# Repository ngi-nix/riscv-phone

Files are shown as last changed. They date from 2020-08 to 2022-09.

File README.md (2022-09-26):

# RISC-V Phone

This flake packages the firmware for the Freedom E310 and the Espressif ESP32 SoCs.

It is currently based against $HEAD of upstream for the [source files](http://majstor.org/gitweb/?p=rvPhone.git;a=tree).

If anything breaks, you can always pin the `riscvphone-src` input to a working revision:

```
url = "git://majstor.org/rvPhone.git?rev=38e19a65fda7a37688320b4b732eb1113bbcbad7";
```
You may find more information about this project [here](http://majstor.org/rvphone/) and [here](http://majstor.org/rvphone/build.html).

For further details, please refer to the documentation in the flake itself.

## Building

To build the firmware for each SoC (and possibly also flash it), type `nix build .#fe310` or `nix build .#esp32`.

## Developing

You can enter a developer shell by typing `nix develop .#fe310` or `nix develop .#esp32`. 

Navigate into `fw/fe310` or `fw/esp32` and type `make` to compile. Typing `make clean` will delete the compiled files.

When typing `make` in `fw/esp32`, a configuration menu will open if no `sdkconfig` configuration file exists, even if empty. You can manually choose the configuration values in this menu at any time by typing `make menuconfig` or pass them automatically via the [sdkconfig.defaults](https://docs.espressif.com/projects/esp-idf/en/latest/esp32/api-reference/kconfig.html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) file.

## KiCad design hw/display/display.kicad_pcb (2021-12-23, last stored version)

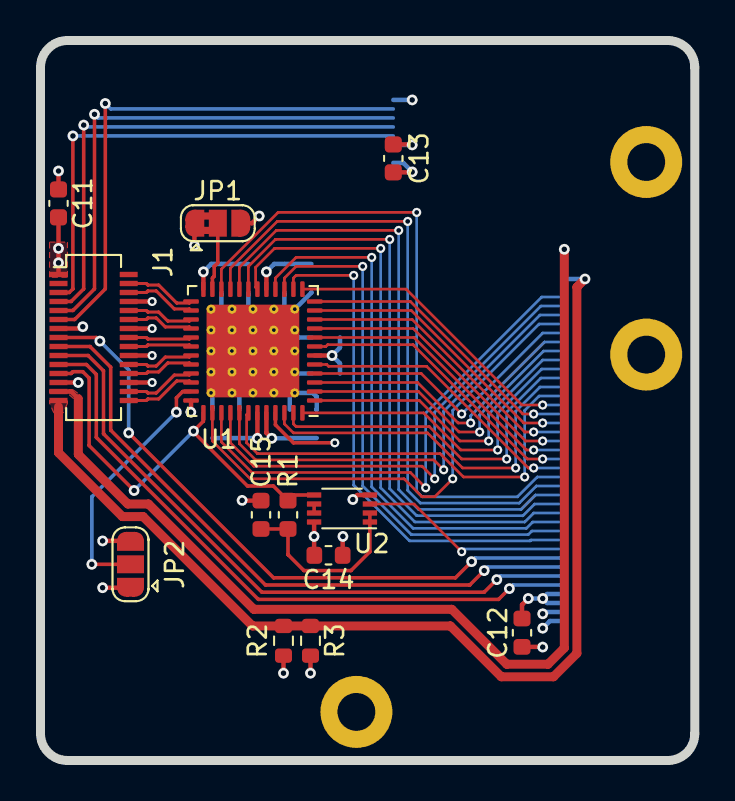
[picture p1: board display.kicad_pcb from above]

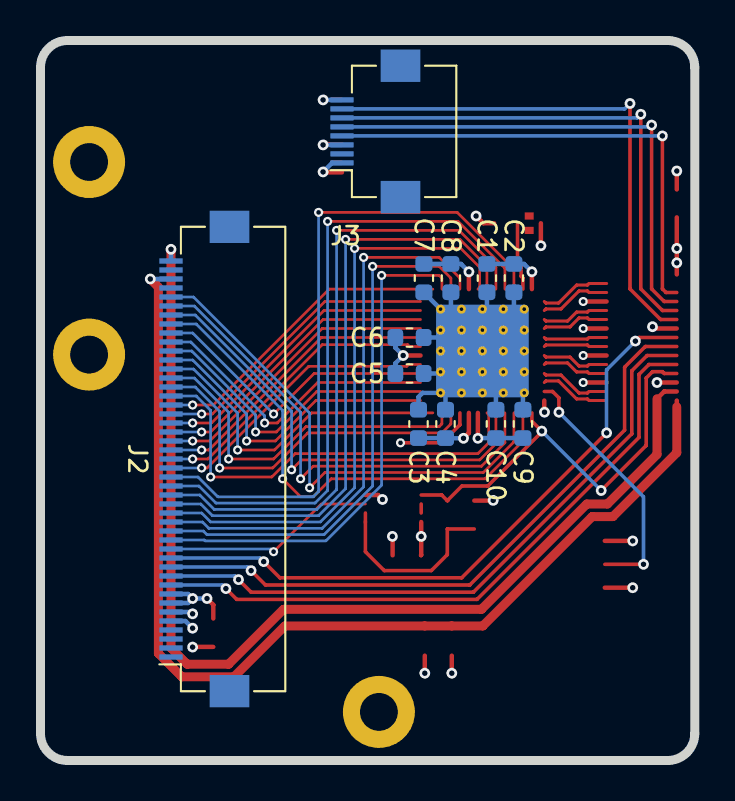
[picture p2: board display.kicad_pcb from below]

Board: 4 copper layers, 36.3 x 40.0 mm, 28 parts (12 on the bottom side), 56 nets.

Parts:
C1, C3, C5, C7, C9, C12, C13, C14, C15: 0.1uF; C_0603_1608Metric
C2, C4, C6, C8, C10: 0.01uF; C_0603_1608Metric
C11: 10uF; C_0603_1608Metric
J1: Input; Molex_SlimStack_55560-0301_2x15_P0.50mm_Vertical
J2: Display; Hirose_FH12-45S-0.5SH_1x45-1MP_P0.50mm_Horizontal
J3: Touch; Hirose_FH12-8S-0.5SH_1x08-1MP_P0.50mm_Horizontal
J4, J5, J6: Spacer
JP1: CLK_POL; SolderJumper-3_P1.3mm_Bridged2Bar12_RoundedPad1.0x1.5mm
JP2: SLEW; SolderJumper-3_P1.3mm_Open_RoundedPad1.0x1.5mm
R1: 10K; R_0603_1608Metric
R2, R3: DNP; R_0603_1608Metric
U1: SN65LVDS822; QFN-48-1EP_7x7mm_P0.5mm_EP5.15x5.15mm_ThermalVias
U2: 74AUP2G132DC; VSSOP-8_2.3x2mm_P0.5mm

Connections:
+3V3: C1.1, C2.1, C3.1, C4.1, C5.1, C6.1, C7.1, C8.1, C9.1, C10.1, C11.1, C12.1, C13.1, C14.1, J1.1, J2.7, J2.8, J3.3, JP1.1, JP2.1, U1.6, U1.17, U1.24, U1.43, U1.44, U2.8
/DISP_B0: J2.37, U1.4
/DISP_B1: J2.36, U1.3
/DISP_B2: J2.35, U1.2
/DISP_B3: J2.34, U1.1
/DISP_B4: J2.33, U1.48
/DISP_B5: J2.32, U1.47
/DISP_B6: J2.31, U1.46
/DISP_B7: J2.30, U1.42
/DISP_DE: J2.38, U1.38
/DISP_G0: J2.29, U1.13
/DISP_G1: J2.28, U1.12
/DISP_G2: J2.27, U1.11
/DISP_G3: J2.26, U1.10
/DISP_G4: J2.25, U1.9
/DISP_G5: J2.24, U1.8
/DISP_G6: J2.23, U1.7
/DISP_G7: J2.22, U1.5
/DISP_HSYNC: J2.40, U1.40
/DISP_PCLK: J2.39, U1.41
/DISP_R0: J2.21, U1.22
/DISP_R1: J2.20, U1.21
/DISP_R2: J2.19, U1.20
/DISP_R3: J2.18, U1.19
/DISP_R4: J2.17, U1.18
/DISP_R5: J2.16, U1.16
/DISP_R6: J2.15, U1.15
/DISP_R7: J2.14, U1.14
/DISP_RST: J2.13, U2.3
/DISP_VSYNC: J2.41, U1.39
/LVDS_A0N: J1.4, U1.25
/LVDS_A0P: J1.6, U1.26
/LVDS_A1N: J1.10, U1.27
/LVDS_A1P: J1.12, U1.28
/LVDS_A2N: J1.16, U1.29
/LVDS_A2P: J1.18, U1.30
/LVDS_A3N: J1.28, U1.33
/LVDS_A3P: J1.30, U1.34
/LVDS_CLKN: J1.22, U1.31
/LVDS_CLKP: J1.24, U1.32
CTP.INT: J1.9, J3.6
CTP.RST: J1.11, J3.7
CTP.SCL: J1.5, J3.4
CTP.SDA: J1.7, J3.5
ENABLE: J1.23, R1.2, U1.37, U2.5
GND: C1.2, C2.2, C3.2, C4.2, C5.2, C6.2, C7.2, C8.2, C9.2, C10.2, C11.2, C12.2, C13.2, C14.2, C15.2, J1.8, J1.13, J1.14, J1.20, J1.25, J1.26, J2.5, J2.6, J3.1, J3.8, J4.1, J5.1, J6.1, JP1.3, JP2.3, R2.2, R3.2, U1.36, U1.45, U1.49, U2.4
LED_A: J1.27, J2.45
LED_K: J1.29, J2.43, R2.1, R3.1
unnamed: C15.1, R1.1, U2.1, U2.2
unnamed: JP1.2, U1.23
unnamed: JP2.2, U1.35
unnamed: U2.6, U2.7
SPI.CS: J1.15, J2.12
SPI.MISO: J1.21, J2.9
SPI.MOSI: J1.19, J2.10
SPI.SCK: J1.17, J2.11

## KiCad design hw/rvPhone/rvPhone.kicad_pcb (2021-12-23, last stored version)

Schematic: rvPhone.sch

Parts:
C1: 1uF; C_0603_1608Metric
C2: 0.047uF; C_0603_1608Metric
C3: 4.7uF; C_0603_1608Metric
C4, C5, C6, C7, C8, C9, C10, C11, C21, C22, C36, C38, C41, C42, C50, C53, C54: 10uF; C_0603_1608Metric
C12: 47uF; C_0805_2012Metric
C13, C15, C16, C17, C18, C19, C20, C23, C24, C27, C28, C29, C30, C31, C32, C33, C34, C35, C37, C39, C40, C43, C44, C45, C46: 0.1uF; C_0603_1608Metric
C14: 0.01uF; C_0603_1608Metric
C25, C26: 10pF; C_0603_1608Metric
C51, C52, C55: 22uF; C_0805_2012Metric
D1: B5817WS; D_SOD-323
D2: LED; LED_0603_1608Metric
J1: USB_OTG; GCT_MicroUSB-USB3080
J2: BATT; PinHeader_1x02_P2.54mm_Vertical
J3: +5V; PinHeader_1x02_P2.54mm_Vertical
J4: AudioJack; 35RASMT4BHNTRX
J5: SPEAKER; PinHeader_1x04_P2.54mm_Vertical
J6: Ext Audio; Molex_SlimStack_54722-0164_2x08_P0.50mm_Vertical
JP1: AUDIO PWR; SolderJumper-3_P1.3mm_Open_RoundedPad1.0x1.5mm
L1: 2.2uH; L_Vishay_IHLP-2525
L2: 2.2uH; Coilcraft-LPS3015
L3: 1uH; Coilcraft-XAL40
R1: 260R; R_0603_1608Metric
R2: 5.23K; R_0603_1608Metric
R3: 30.1K; R_0603_1608Metric
R4: 2.2K; R_0603_1608Metric
R5: 560K; R_0603_1608Metric
R6: 180K; R_0603_1608Metric
R7, R8, R9, R10, R11, R15, R16, R18, R19, R20, R21, R22, R23, R24, R25, R26, R30, R34, R35: 100K; R_0603_1608Metric
R12: 100R; R_0603_1608Metric
R13, R14, R33: 10K; R_0603_1608Metric
R17, R28, R29: 47K; R_0603_1608Metric
R27: 210K; R_0603_1608Metric
R31: 50K; R_0603_1608Metric
R32: 0R; R_0603_1608Metric
SW1: RESET; SW_SPST_PTS810
SW2: WAKE; Panasonic_EVPAE
TP2: PMU_OUT0; TestPoint_Pad_D1.5mm
U1: BQ25895; Texas_S-PWQFN-N24_EP2.7x2.7mm_ThermalVias
U2: TPS62293; TPS62290
U3: TPS630250
U4: FE310-G002; QFN-48-1EP_6x6mm_P0.4mm_EP4.2x4.2mm_ThermalVias
U5: IS25LP128-JKLE; WSON-8-1EP_6x5mm_P1.27mm_EP3.4x4mm
U6: SN74LVC2G07DCK; Texas_R-PDSO-G6
U7: TMUX1574RSV; UQFN-16_1.8x2.6mm_P0.4mm
U8, U9: 74HC00; DHVQFN-14_2.5x3.0mm_P0.5mm_EP1.0x1.5mm
U10, U11: 74HC595; DHVQFN-16_2.5x3.5mm_P0.5mm_EP1.0x2.0mm
U12: ICS-43434
U13, U14: MAX98357A; TQFN-16-1EP_3x3mm_P0.5mm_EP1.23x1.23mm_ThermalVias
U15, U16: MAX14689A; TDFN-10-1EP_2x2.5mm_P0.4mm_EP1.3x1.4mm_ThermalVias
U17: SN74LVC1G04DCK; Texas_R-PDSO-G5
U18: TMUX1119DCK; Texas_R-PDSO-G6
U19: 74LVC1G02; Texas_R-PDSO-G5
U20: SN74LVC2G66DCU; VSSOP-8_2.3x2mm_P0.5mm
X1: SiT1533
Y1: 16MHz; TXC_7M

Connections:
+1V8: C9.1, C19.1, C20.1, C21.1, C55.1, L2.2, R12.1, U2.3 (FB), U4.6 (VDD), U4.30 (VDD), U4.46 (VDD); also elsewhere on the board
+VSYS: C4.1, C5.1, C8.1, C10.1, D2.2 (A), L1.2, U1.8 (OTG), U1.15 (SYS), U1.16 (SYS), U2.4 (EN), U2.5 (VIN), U3.4 (VIN), U3.5 (VIN), U3.6 (VIN), U3.7 (VINA), U3.8 (EN); also elsewhere on the board
/AON_PMU_OUT_0: TP2.1, U4.22 (AON_PMU_OUT_0)
/AON_PMU_OUT_1: U4.17 (AON_PMU_OUT_1)
/AUDIO_OUT_L+: U13.9 (OUTP), U15.3
/AUDIO_OUT_L-: U13.10 (OUTN), U15.10
/AUDIO_OUT_R+: U14.9 (OUTP), U16.3
/AUDIO_OUT_R-: U14.10 (OUTN), U16.10
/BQ_QON: U1.12 (/QON), U6.4 (2Y)
/BQ_SW: C2.1, D1.2 (A), L1.1, U1.19 (SW), U1.20 (SW)
/EXT_AUDIO_EN: J6.10, U19.4
/HP_DET: J4.RN, J4.TN, R30.1, U17.2 (A)
/HP_L: C42.2, U15.5
/HP_R: C41.2, U16.5
/MIC_CLK: R23.2, U7.11 (S4B), U8.1, U9.12, U9.13, U12.4 (SCK)
/MIC_SD: U12.6 (SD), U20.2
/MIC_WS: R21.2, U7.1 (S1B), U12.1 (WS)
/PLL_AVDD: C23.1, C24.1, R12.2, U4.7 (PLL_AVDD)
/PLL_AVSS: C23.2, C24.2, U4.8 (PLL_AVSS)
/PSD_LFALTCLK: U4.20 (AON_PSD_LFALTCLK), X1.3 (CLKOUT)
/QSPI_CLK: U4.48 (QSPI_CLK), U5.6 (SCK)
/QSPI_CS: R8.2, U4.5 (QSPI_CS), U5.1 (S#)
/QSPI_DQ_0: U4.4 (QSPI_DQ_0), U5.5 (MOSI/IO0)
/QSPI_DQ_1: U4.3 (QSPI_DQ_1), U5.2 (MISO/IO1)
/QSPI_DQ_2: U4.2 (QSPI_DQ_2), U5.3 (WP#/IO2)
/QSPI_DQ_3: R9.2, U4.1 (QSPI_DQ_3), U5.7 (HOLD#/IO3)
/RESET: C14.1, R10.1, SW1.2, U4.24 (AON_ERST_N), U6.6 (1Y)
/SD_IN: U7.4 (S2B), U11.9, U13.1 (DIN), U14.1 (DIN)
/SD_OUT: R22.2, U7.8 (S3B), U10.14, U20.1
/SPK_CLK: U9.11, U13.16 (BCLK), U14.16 (BCLK)
/SPK_EN: C39.1, C40.1, R27.2, U7.15 (SEL), U8.8, U9.4, U9.5, U13.4 (SD_MODE), U15.2, U16.2, U19.1
/SPK_GAIN: U13.2 (GAIN_SLOT), U14.2 (GAIN_SLOT), U18.5
/SPK_GAIN_SEL: U9.8, U18.1
/SPK_L+: J5.1, J6.5, J6.7, U15.1
/SPK_L-: J5.2, J6.9, J6.11, U15.8
/SPK_R+: J5.3, U16.1
/SPK_R-: J5.4, U16.8
/XTAL_XI: C25.1, U4.9 (16M_XTAL_XI), Y1.1
/XTAL_XO: C26.1, U4.10 (16M_XTAL_XO), Y1.2
/~HP_DET: U9.9, U15.7, U16.7, U17.4 (Y)
BQ.INT: U1.7 (INT); also elsewhere on the board
BT81X.AUDIO: J6.6; also elsewhere on the board
BT81X.GPIO2: U9.10, U19.2; also elsewhere on the board
BT81X.INT: R16.1, U7.12 (S4A); also elsewhere on the board
CTP.RST: R15.1, U7.16 (S1A); also elsewhere on the board
DISP_CS: U9.3; also elsewhere on the board
GND: C1.2, C3.2, C4.2, C5.2, C6.2, C7.2, C8.2, C9.2, C10.2, C11.2, C12.2, C13.2, C14.2, C15.2, C16.2, C17.2, C18.2, C19.2, C20.2, C21.2, C22.2, C25.2, C26.2, C27.2, C28.2, C29.2, C30.2, C31.2, C32.2, C33.2, C34.2, C35.2, C36.2, C37.2, C38.2, C39.2, C40.2, C43.2, C44.2, C45.2, C46.2, C50.2, C51.2, C52.2, C53.2, C54.2, C55.2, J1.5 (GND), J2.2, J3.2, J4.S, J6.1, J6.3, R1.2, R3.2, R6.2, R18.1, R19.1, R20.1, R21.1, R22.1, R23.1, R26.1, R28.2, R29.2, R32.2, R33.2, R34.1, R35.1, SW1.1, SW2.1, U1.9 (/CE), U1.17 (PGND), U1.18 (PGND), U1.25 (EP), U2.2 (MODE), U2.6 (GND), U2.7 (EP), U3.2 (PGND), U3.9 (GND), U3.10 (PFM), U4.21 (AON_PSD_LFCLKSEL), U4.49 (GND), U5.4 (VSS), U5.9 (EP), U6.2 (GND), U7.6 (GND), U7.13 (/EN), U8.7 (GND), U8.15, U9.7 (GND), U9.15, U10.8, U10.12, U10.17, U11.8, U11.12, U11.17, U12.2 (LR), U12.3 (GND), U13.3 (GND), U13.11 (GND), U13.15 (GND), U13.17 (EP), U14.3 (GND), U14.11 (GND), U14.15 (GND), U14.17 (EP), U15.4, U15.9, U15.11, U16.4, U16.9, U16.11, U17.3 (GND), U18.3, U19.3, U20.3, U20.4, U20.5, U20.6, X1.2 (GND), Y1.3; also elsewhere on the board
GPIO_0: U4.25 (GPIO_0/PWM0.0); also elsewhere on the board
GPIO_16: U4.38 (GPIO_16/UART0.RX), U7.7 (D3)
GPIO_17: U4.39 (GPIO_17/UART0.TX), U7.5 (D2)
GPIO_18: R19.2, U4.40 (GPIO_18), U8.5, U8.12, U8.13
GPIO_20: U4.42 (GPIO_20/PWM1.0); also elsewhere on the board
GPIO_22: U4.44 (GPIO_22/PWM1.3); also elsewhere on the board
GPIO_23: R18.2, U4.45 (GPIO_23); also elsewhere on the board
I2C0.SCL: R13.2, U1.5 (SCL), U4.37 (GPIO_13/PWM2.3); also elsewhere on the board
I2C0.SDA: R14.2, U1.6 (SDA), U4.36 (GPIO_12/PWM2.2); also elsewhere on the board
JTAG_TCK: U4.13 (JTAG_TCK); also elsewhere on the board
JTAG_TDI: U4.16 (JTAG_TDI); also elsewhere on the board
JTAG_TDO: U4.14 (JTAG_TDO); also elsewhere on the board
JTAG_TMS: U4.15 (JTAG_TMS); also elsewhere on the board
JTAG_TRST_N: R7.2, U6.1 (1A); also elsewhere on the board
unnamed: C2.2, U1.21 (BTST)
unnamed: C3.1, R2.1, U1.22 (REGN)
unnamed: C6.1, C7.1, J2.1, U1.13 (BAT), U1.14 (BAT)
unnamed: C41.1, J4.R, R28.1
unnamed: C42.1, J4.T, R29.1
unnamed: D2.1 (K), R4.2
unnamed: L2.1, U2.1 (SW)
unnamed: L3.1, U3.3 (L1)
unnamed: L3.2, U3.1 (L2)
unnamed: R1.1, U1.10 (ILIM)
unnamed: R2.2, R3.1, R33.1, U1.11 (TS)
unnamed: R4.1, U1.4 (STAT)
unnamed: R5.2, R6.1, U3.11 (FB)
unnamed: R27.1, U14.4 (SD_MODE)
unnamed: R31.2, U18.6
unnamed: R32.1, U18.4
unnamed: U1.2 (D+), U1.3 (D-)
unnamed: U8.3, U8.4
unnamed: U8.10, U8.11
unnamed: U9.2, U9.6
unnamed: U10.9, U11.14
unnamed: U8.6, U10.11, U11.11
PWM0.1: U4.26 (GPIO_1/PWM0.1), U7.10 (D4)
PWM1.1: U4.41 (GPIO_19/PWM1.1), U7.2 (D1)
PWM1.2: R17.2, U4.43 (GPIO_21/PWM1.2), U8.2, U8.9, U20.7
PWM2.1: R20.2, U4.35 (GPIO_11/PWM2.1), U9.1, U13.14 (LRCLK), U14.14 (LRCLK)
SPI1.MISO: R24.2, U4.29 (GPIO_4/SPI1.MISO); also elsewhere on the board
SPI1.MOSI: R25.2, U4.28 (GPIO_3/SPI1.MOSI/PWM0.3); also elsewhere on the board
SPI1.SCK: R26.2, U4.31 (GPIO_5/SPI1.SCK); also elsewhere on the board
SPI1.SS0: U4.27 (GPIO_2/SPI1.SS0/PWM0.2); also elsewhere on the board
SPI1.SS2: U4.33 (GPIO_9/SPI1.SS2); also elsewhere on the board
SPI1.SS3: U4.34 (GPIO_10/SPI1.SS3/PWM2.0); also elsewhere on the board
UART0.RXD: R35.2, U7.9 (S3A); also elsewhere on the board
UART0.TXD: R34.2, U7.3 (S2A); also elsewhere on the board
USB_D+: J1.3 (D+); also elsewhere on the board
USB_D-: J1.2 (D-); also elsewhere on the board
VBUS: C1.1, C50.1, J1.1 (VBUS), U1.1 (VBUS); also elsewhere on the board
WAKE: R11.1, SW2.2, U4.18 (AON_PMU_DWAKEUP_N), U6.3 (2A); also elsewhere on the board

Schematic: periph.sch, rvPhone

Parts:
C201, C204, C205, C206, C207, C208, C209, C210, C211, C212, C213, C214, C219, C220, C223, C224, C226, C227, C229, C230, C231: 0.1uF; C_0603_1608Metric
C202, C228: 22uF; C_0805_2012Metric
C203, C221, C222: 1uF; C_0603_1608Metric
C215, C216, C217: 33pF; C_0603_1608Metric
C218: 470uF; CP_EIA-7343-31_Kemet-D
C225: 0.01uF; C_0603_1608Metric
J201: Modem; TE_mPCIe-1775862
J202: SIM_Card; Wurth_NanoSIM-693043020611
J203: Motor; SolderWirePad_1x02_SMD_1x2mm
J204: Micro_SD_Card_Det; Molex_MicroSD-5027740891
J205: Prog; Hirose_FH12-12S-0.5SH_1x12-1MP_P0.50mm_Horizontal
J206: Expansion; Molex_SlimStack_54722-0164_2x08_P0.50mm_Vertical
J207: Camera; Molex_SlimStack_54722-0164_2x08_P0.50mm_Vertical
J208, J209: Spacer; Spacer_small
JP201: PCM_EN; SolderJumper-3_P1.3mm_Bridged2Bar12_RoundedPad1.0x1.5mm
JP202: SIMCom_EN; SolderJumper-3_P1.3mm_Bridged2Bar12_RoundedPad1.0x1.5mm
JP203: Q.DTR; SolderJumper-2_P1.3mm_Open_RoundedPad1.0x1.5mm
JP204: Q.RI; SolderJumper-2_P1.3mm_Open_RoundedPad1.0x1.5mm
JP205: Q.RXD; SolderJumper-2_P1.3mm_Open_RoundedPad1.0x1.5mm
JP206: Q.TXD; SolderJumper-2_P1.3mm_Open_RoundedPad1.0x1.5mm
R201, R209: 10K; R_0603_1608Metric
R202, R203, R207: 47K; R_0603_1608Metric
R204, R205, R206: 22R; R_0603_1608Metric
R208: 4.7K; R_0603_1608Metric
SW201: ESP32_RST; SW_SPST_PTS810
SW202: MODEM_RST; SW_SPST_PTS810
U201: ESP32-WROOM
U202: SN74CBTLV3125RGY; Texas_S-PVQFN-N14_ThermalVias
U203, U204: TXB0104RGY; Texas_S-PVQFN-N14_ThermalVias
U205: DRV2605LDGS; VSSOP-10_3x3mm_P0.5mm
U206: LSM9DS1; LGA-24L_3x3.5mm_P0.43mm
U207: FT230XQ; QFN-16-1EP_4x4mm_P0.65mm_EP2.1x2.1mm
U208: TMUX154ERSW; UQFN-10_1.4x1.8mm_P0.4mm

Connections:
+1V8: C206.1, C208.1, JP201.1, JP202.1, U203.1 (VCCA), U204.1 (VCCA); also elsewhere on the board
+VSYS: J207.2, J207.4; also elsewhere on the board
/periph/ESP32_EN: C203.1, C219.1, R201.2, SW201.1, U201.3 (EN)
/periph/ESP32_PCM_CLK: U201.9 (IO33), U203.13 (B1)
/periph/ESP32_PCM_DI: U201.6 (IO34), U203.12 (B2)
/periph/ESP32_PCM_DO: U201.24 (IO2), U203.11 (B3)
/periph/ESP32_PCM_SYNC: U201.26 (IO4), U203.10 (B4)
/periph/ESP32_UART2_DTR: JP203.1, U201.8 (IO32), U204.12 (B2)
/periph/ESP32_UART2_RI: JP204.1, U201.7 (IO35), U204.13 (B1)
/periph/ESP32_UART2_RXD: JP206.1, U201.28 (IO17), U204.11 (B3)
/periph/ESP32_UART2_TXD: JP205.1, U201.27 (IO16), U204.10 (B4)
/periph/ESP32_VSPI_MISO: U201.31 (IO19), U202.5 (2A)
/periph/ESP32_VSPI_MOSI: U201.37 (IO23), U202.9 (3A)
/periph/ESP32_VSPI_SCK: U201.30 (IO18), U202.12 (4A)
/periph/ESP32_VSPI_SS0: R202.2, U201.29 (IO5), U202.3 (1B)
/periph/PCM_CLK: J201.45, U203.2 (A1)
/periph/PCM_DI: J201.49, U203.4 (A3)
/periph/PCM_DO: J201.47, U203.3 (A2)
/periph/PCM_SYNC: J201.51, U203.5 (A4)
/periph/PERST: C220.1, J201.22, SW202.1
/periph/Quectel_UART_DTR: J201.31, JP203.2
/periph/Quectel_UART_RI: J201.17, JP204.2, U204.5 (A4)
/periph/Quectel_UART_RXD: J201.11, JP205.2
/periph/Quectel_UART_TXD: J201.13, JP206.2
/periph/SIMCom_UART_DTR: J201.46, U204.3 (A2)
/periph/SIMCom_UART_RI: J201.44, U204.2 (A1)
/periph/SIMCom_UART_TXD: J201.19, U204.4 (A3)
/periph/USB_CBUS0: U207.12 (CBUS0), U208.8 (/EN)
/periph/USB_CBUS1: U207.11 (CBUS1), U208.10 (SEL)
/periph/USB_CBUS3: R208.2, R209.1, U207.14 (CBUS3)
/periph/USB_RXD: U207.2 (RXD), U208.5 (B)
/periph/USB_TXD: U207.15 (TXD), U208.3 (A)
BQ.INT: U201.10 (IO25); also elsewhere on the board
BT81X.GPIO0: J207.10; also elsewhere on the board
BT81X.GPIO3: U205.4 (IN/TRIG); also elsewhere on the board
ESP32.HSPI.MISO: U201.14 (IO12); also elsewhere on the board
ESP32.HSPI.MOSI: U201.16 (IO13); also elsewhere on the board
ESP32.HSPI.SCK: U201.13 (IO14); also elsewhere on the board
ESP32.HSPI.SS0: U201.23 (IO15); also elsewhere on the board
ESP32.IO26: U201.11 (IO26); also elsewhere on the board
ESP32.IO27: U201.12 (IO27); also elsewhere on the board
ESP32.UART0.RXD: J205.1, U201.34 (RXD0), U208.2 (A1)
ESP32.UART0.TXD: J205.2, U201.35 (TXD0), U208.6 (B1)
GND: C201.2, C202.2, C203.2, C204.2, C205.2, C206.2, C207.2, C208.2, C209.2, C210.2, C211.2, C212.2, C213.2, C214.2, C215.2, C216.2, C217.2, C218.2, C219.2, C220.2, C221.2, C222.2, C223.2, C224.2, C225.2, C226.2, C227.2, C228.2, C229.2, C230.2, C231.2, J201.4, J201.9, J201.15, J201.18, J201.21, J201.26, J201.27, J201.29, J201.34, J201.35, J201.37, J201.40, J201.43, J201.50, J201.53, J202.5 (GND), J204.6, J204.11, J205.3, J205.9, J206.6, J206.11, J206.16, J207.6, J207.11, J207.16, J208.1, J209.1, JP201.3, JP202.3, R209.2, SW201.2, SW202.2, U201.1 (GND), U201.15 (GND), U201.38 (GND), U201.39 (EP), U202.2 (1A), U202.7 (GND), U202.15 (EP), U203.7 (GND), U203.15 (Pad), U204.7 (GND), U204.15 (Pad), U205.8 (GND), U206.14 (RES), U206.15 (RES), U206.16 (RES), U206.17 (RES), U206.18 (RES), U206.19 (GND), U206.20 (GND), U207.3 (GND), U207.4 (~CTS), U207.13 (GND), U207.17 (GND), U208.4 (GND); also elsewhere on the board
GPIO_0: J204.2, R207.2; also elsewhere on the board
GPIO_20: U201.36 (IO22); also elsewhere on the board
GPIO_22: U201.33 (IO21); also elsewhere on the board
I2C0.SCL: J206.14, J207.14, U205.2 (SCL), U206.2 (SCL/SPC); also elsewhere on the board
I2C0.SDA: J206.12, J207.12, U205.3 (SDA), U206.4 (SDA/SDI/SDO); also elsewhere on the board
JTAG_TCK: J205.4; also elsewhere on the board
JTAG_TDI: J205.7; also elsewhere on the board
JTAG_TDO: J205.5; also elsewhere on the board
JTAG_TMS: J205.6; also elsewhere on the board
JTAG_TRST_N: J205.8; also elsewhere on the board
unnamed: C214.1, J201.8, J202.1 (VCC)
unnamed: C215.1, J202.2 (RST), R206.1
unnamed: C216.1, J202.3 (CLK), R205.1
unnamed: C217.1, J202.7 (I/O), R204.1
unnamed: C222.1, U205.1 (REG)
unnamed: C225.1, U206.21 (CAP)
unnamed: C226.1, U206.24 (C1)
unnamed: J201.10, R204.2
unnamed: J201.12, R205.2
unnamed: J201.14, R206.2
unnamed: J203.1, U205.7 (OUT+)
unnamed: J203.2, U205.9 (OUT-)
unnamed: JP201.2, U203.8 (OE)
unnamed: JP202.2, U204.8 (OE)
SPI1.MISO: J204.7, J206.7, J207.7, U202.6 (2B); also elsewhere on the board
SPI1.MOSI: J204.3, J206.5, J207.5, U202.8 (3B); also elsewhere on the board
SPI1.SCK: J204.5, J206.9, J207.9, U202.11 (4B); also elsewhere on the board
SPI1.SS0: R203.2, U202.1 (/1OE), U202.4 (/2OE), U202.10 (/3OE), U202.13 (/4OE); also elsewhere on the board
SPI1.SS2: J207.8; also elsewhere on the board
UART0.RXD: J205.11, J206.15, U208.1 (A0); also elsewhere on the board
UART0.TXD: J205.10, J206.13, U208.7 (B0); also elsewhere on the board
USB_D+: U207.6 (USBDP); also elsewhere on the board
USB_D-: U207.7 (USBDM); also elsewhere on the board
VBUS: R208.1; also elsewhere on the board
WAKE: U201.25 (IO0); also elsewhere on the board
iMX8.USB1.D_N: J201.36; also elsewhere on the board
iMX8.USB1.D_P: J201.38; also elsewhere on the board

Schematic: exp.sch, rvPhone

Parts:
C301: 4.7uF; C_0603_1608Metric
C302, C303, C304, C305, C306, C307, C308, C309, C310, C311, C312, C313, C319: 0.1uF; C_0603_1608Metric
C314, C315, C316, C317, C318, C320: 22uF; C_0805_2012Metric
J301: iMX8; TE_SODIMMDDR3-2013289
J302: Micro_SD_Card_Det; Molex_MicroSD-5027740891
J303: Console; Hirose_FH12-6S-0.5SH_1x06-1MP_P0.50mm_Horizontal
JP301: USB_VBUS; SolderJumper-2_P1.3mm_Open_RoundedPad1.0x1.5mm
JP302: USB_ID; SolderJumper-2_P1.3mm_Open_RoundedPad1.0x1.5mm
R301, R302: 47K; R_0603_1608Metric
R303, R304: 10K; R_0603_1608Metric
R305, R306, R307: 100K; R_0603_1608Metric
SW301: iMX8_ALT_BOOT; SW_SPST_PTS810
SW302: iMX8_RST; SW_SPST_PTS810
SW303: iMX8_PWR; SW_SPST_PTS810

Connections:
+VSYS: C302.1, C303.1, C304.1, C305.1, C306.1, C307.1, C308.1, C309.1, C310.1, C311.1, C312.1, C313.1, C314.1, C315.1, C316.1, C317.1, C318.1, J301.10 (PIN10), J301.28 (PIN28), J301.46 (PIN46), J301.64 (PIN64), J301.78 (PIN78), J301.96 (PIN96), J301.114 (PIN114), J301.132 (PIN132), J301.150 (PIN150), J301.168 (PIN168), J301.186 (PIN186), J301.204 (PIN204); also elsewhere on the board
/exp/ALT_BOOT: J301.185 (PIN185), SW301.1
/exp/POWER: J301.165 (PIN165), SW303.1
/exp/RESET: J301.171 (PIN171), SW302.1
/exp/SD2_CLK: J301.80 (PIN80), J302.5
/exp/SD2_CMD: J301.82 (PIN82), J302.3
/exp/SD2_DAT0: J301.84 (PIN84), J302.7
/exp/SD2_DAT1: J301.86 (PIN86), J302.8
/exp/SD2_DAT2: J301.88 (PIN88), J302.1
/exp/SD2_DAT3: J301.90 (PIN90), J302.2
/exp/SD2_DET: J301.61 (PIN61), J302.9, R301.2
/exp/UART3_RX: J301.117 (PIN117), J303.3
/exp/UART3_TX: J301.111 (PIN111), J303.4
ESP32.HSPI.MISO: J301.15 (PIN15); also elsewhere on the board
ESP32.HSPI.MOSI: J301.11 (PIN11); also elsewhere on the board
ESP32.HSPI.SCK: J301.13 (PIN13); also elsewhere on the board
ESP32.HSPI.SS0: J301.17 (PIN17), R302.2; also elsewhere on the board
ESP32.IO26: J301.7 (PIN7); also elsewhere on the board
ESP32.IO27: J301.9 (PIN9); also elsewhere on the board
GND: C301.2, C302.2, C303.2, C304.2, C305.2, C306.2, C307.2, C308.2, C309.2, C310.2, C311.2, C312.2, C313.2, C314.2, C315.2, C316.2, C317.2, C318.2, C319.2, C320.2, J301.1 (PIN1), J301.19 (PIN19), J301.37 (PIN37), J301.55 (PIN55), J301.67 (PIN67), J301.71 (PIN71), J301.87 (PIN87), J301.105 (PIN105), J301.123 (PIN123), J301.141 (PIN141), J301.159 (PIN159), J301.177 (PIN177), J302.6, J302.10, J302.11, J303.5, J303.6, JP302.1, R306.1, R307.1, SW302.2, SW303.2; also elsewhere on the board
unnamed: C301.1, J301.183 (PIN183)
iMX8.GPIO5.IO28: J301.5 (PIN5), R306.2; also elsewhere on the board
iMX8.GPIO5.IO29: J301.3 (PIN3), R305.2; also elsewhere on the board
iMX8.I2C3.SCL: J301.43 (PIN43), R303.2; also elsewhere on the board
iMX8.I2C3.SDA: J301.49 (PIN49), R304.2; also elsewhere on the board
iMX8.LVDS0.A0N: J301.41 (PIN41); also elsewhere on the board
iMX8.LVDS0.A0P: J301.39 (PIN39); also elsewhere on the board
iMX8.LVDS0.A1N: J301.47 (PIN47); also elsewhere on the board
iMX8.LVDS0.A1P: J301.45 (PIN45); also elsewhere on the board
iMX8.LVDS0.A2N: J301.53 (PIN53); also elsewhere on the board
iMX8.LVDS0.A2P: J301.51 (PIN51); also elsewhere on the board
iMX8.LVDS0.A3N: J301.59 (PIN59); also elsewhere on the board
iMX8.LVDS0.A3P: J301.57 (PIN57); also elsewhere on the board
iMX8.LVDS0.CLKN: J301.35 (PIN35); also elsewhere on the board
iMX8.LVDS0.CLKP: J301.33 (PIN33); also elsewhere on the board
iMX8.PWM1: J301.200 (PIN200), R307.2; also elsewhere on the board
iMX8.USB1.D_N: J301.178 (PIN178); also elsewhere on the board
iMX8.USB1.D_P: J301.176 (PIN176); also elsewhere on the board
iMX8.USB1.ID: J301.174 (PIN174), JP302.2
iMX8.USB1.VBUS: J301.180 (PIN180), JP301.2

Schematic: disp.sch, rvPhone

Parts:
C401, C402, C415: 1uF; C_0603_1608Metric
C403, C406, C408, C411, C412, C413, C414, C416, C417, C419, C420, C422, C424, C426, C427, C428, C429, C430, C431, C432, C433, C434: 0.1uF; C_0603_1608Metric
C404, C418, C441: 10uF; C_0603_1608Metric
C409, C410: 10pF; C_0603_1608Metric
C421, C423, C425: 0.01uF; C_0603_1608Metric
D401: MBR0540; D_SOD-123
D402: 3SMAJ5935B-TP; D_SMA
J401: Display; Molex_SlimStack_54722-0304_2x15_P0.50mm_Vertical
J402, J403, J404: Spacer; Spacer_small
JP402: VOD_SEL; SolderJumper-3_P1.3mm_Bridged2Bar12_RoundedPad1.0x1.5mm
L401: 10uH; Murata-LQH66SN
R401, R402, R406, R407, R408, R409, R410: 47K; R_0603_1608Metric
R403: 22R; R_0603_1608Metric
R404: 15R; R_0603_1608Metric
R405: 68R; R_0603_1608Metric
U401: FAN5333BSX; SOT-23-5
U402: SN74LVC3G06DCU; VSSOP-8_2.4x2.1mm_P0.5mm
U403: BT817Q; QFN-64-1EP_9x9mm_P0.5mm_EP6x6mm_ThermalVias
U404: IS25LP128-JKLE; WSON-8-1EP_6x5mm_P1.27mm_EP3.4x4mm
U405: DS90C185; QFN-48-1EP_6x6mm_P0.4mm_EP4.6x4.6mm_ThermalVias
U406: TS3DV520ERUA; Texas_R-PWQFN-N42
U407: TMUX1574RSV; UQFN-16_1.8x2.6mm_P0.4mm
Y401: 12MHz; TXC_7M

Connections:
+1V8: C403.1, C414.1, C421.1, C422.1, C423.1, C424.1, C425.1, C426.1, C441.2, J401.3, JP402.3, R401.1, U402.8 (VCC), U403.28 (VCCIO2), U405.13 (VDDPLL), U405.25 (VDDTX), U405.48 (VDD); also elsewhere on the board
+VSYS: C404.1, L401.1, R402.1, U401.5 (VIN); also elsewhere on the board
/disp/BT81X_1V2: C415.1, C416.1, C417.1, C418.1, C419.1, U403.2 (VIN1V2), U403.25 (VOUT1V2), U403.57 (VIN1V2)
/disp/BT81X_QSPI_CLK: U403.14 (SPIMSCK), U404.6 (SCK)
/disp/BT81X_QSPI_CS: R408.2, U403.15 (SPIMCS), U404.1 (S#)
/disp/BT81X_QSPI_DQ_0: U403.16 (SPIMMOSI), U404.5 (MOSI/IO0)
/disp/BT81X_QSPI_DQ_1: U403.18 (SPIMMISO), U404.2 (MISO/IO1)
/disp/BT81X_QSPI_DQ_2: R410.2, U403.19 (SPIMIO2), U404.3 (WP#/IO2)
/disp/BT81X_QSPI_DQ_3: R409.2, U403.20 (SPIMIO3), U404.7 (HOLD#/IO3)
/disp/BT81X_X1: C409.1, U403.21 (X1/CLK), Y401.1
/disp/BT81X_X2: C410.1, U403.22 (X2), Y401.2
/disp/CTP_INT: J401.9, U407.7 (D3)
/disp/CTP_RST: J401.11, U407.10 (D4)
/disp/CTP_SCL: J401.5, U407.2 (D1)
/disp/CTP_SDA: J401.7, U407.5 (D2)
/disp/DISP_LVDS_A0N: J401.4, U406.15 (A9)
/disp/DISP_LVDS_A0P: J401.6, U406.14 (A8)
/disp/DISP_LVDS_A1N: J401.10, U406.11 (A7)
/disp/DISP_LVDS_A1P: J401.12, U406.10 (A6)
/disp/DISP_LVDS_A2N: J401.16, U406.9 (A5)
/disp/DISP_LVDS_A2P: J401.18, U406.8 (A4)
/disp/DISP_LVDS_A3N: J401.28, U406.3 (A1)
/disp/DISP_LVDS_A3P: J401.30, U406.2 (A0)
/disp/DISP_LVDS_CLKN: J401.22, U406.6 (A3)
/disp/DISP_LVDS_CLKP: J401.24, U406.5 (A2)
/disp/DS90_LVDS_A0N: U405.36 (TX0-), U406.21 (9B2)
/disp/DS90_LVDS_A0P: U405.35 (TX0+), U406.20 (8B2)
/disp/DS90_LVDS_A1N: U405.34 (TX1-), U406.23 (7B2)
/disp/DS90_LVDS_A1P: U405.33 (TX1+), U406.24 (6B2)
/disp/DS90_LVDS_A2N: U405.32 (TX2-), U406.27 (5B2)
/disp/DS90_LVDS_A2P: U405.31 (TX2+), U406.28 (4B2)
/disp/DS90_LVDS_A3N: U405.28 (TX3-), U406.36 (1B2)
/disp/DS90_LVDS_A3P: U405.27 (TX3+), U406.37 (0B2)
/disp/DS90_LVDS_CLKN: U405.30 (TXCLK-), U406.32 (3B2)
/disp/DS90_LVDS_CLKP: U405.29 (TXCLK+), U406.33 (2B2)
BT81X.AUDIO: U403.26 (AUDIO_L); also elsewhere on the board
BT81X.B0: U403.47 (B0), U405.4 (D12)
BT81X.B1: U403.46 (B1), U405.5 (D13)
BT81X.B2: U403.45 (B2), U405.7 (D14)
BT81X.B3: U403.44 (B3), U405.8 (D15)
BT81X.B4: U403.43 (B4), U405.9 (D16)
BT81X.B5: U403.42 (B5), U405.10 (D17)
BT81X.B6: U403.41 (B6), U405.20 (D25)
BT81X.B7: U403.40 (B7), U405.21 (D26)
BT81X.BL_PWM: U402.3 (2A), U403.34 (BL_PWM)
BT81X.DE: U403.35 (DE), U405.14 (D20)
BT81X.DISP: U403.38 (DISP), U405.37 (PDB), U406.12 (SEL), U407.15 (SEL)
BT81X.G0: U403.56 (G0), U405.45 (D6)
BT81X.G1: U403.55 (G1), U405.46 (D7)
BT81X.G2: U403.54 (G2), U405.47 (D8)
BT81X.G3: U403.53 (G3), U405.1 (D9)
BT81X.G4: U403.52 (G4), U405.2 (D10)
BT81X.G5: U403.51 (G5), U405.3 (D11)
BT81X.G6: U403.50 (G6), U405.18 (D23)
BT81X.G7: U403.49 (G7), U405.19 (D24)
BT81X.GPIO0: U403.7 (GPIO0/IO2); also elsewhere on the board
BT81X.GPIO1: J401.23, U403.8 (GPIO1/IO3)
BT81X.GPIO2: U403.10 (GPIO2); also elsewhere on the board
BT81X.GPIO3: U403.13 (GPIO3); also elsewhere on the board
BT81X.HSYNC: U403.37 (HSYNC), U405.11 (D18)
BT81X.INT: U403.11 (INT_N); also elsewhere on the board
BT81X.PCLK: U403.39 (PCLK), U405.6 (CLK)
BT81X.R0: U403.1 (R0), U405.38 (D0)
BT81X.R1: U403.64 (R1), U405.40 (D1)
BT81X.R2: U403.63 (R2), U405.41 (D2)
BT81X.R3: U403.62 (R3), U405.42 (D3)
BT81X.R4: U403.61 (R4), U405.43 (D4)
BT81X.R5: U403.60 (R5), U405.44 (D5)
BT81X.R6: U403.59 (R6), U405.16 (D21)
BT81X.R7: U403.58 (R7), U405.17 (D22)
BT81X.VSYNC: U403.36 (VSYNC), U405.12 (D19)
CTP.RST: U407.11 (S4B); also elsewhere on the board
DISP_CS: J401.15; also elsewhere on the board
DISP_LED_A: C401.1, C402.1, D401.1 (K), D402.1 (K), J401.27
DISP_LED_K: C406.1, D402.2 (A), J401.29, R403.1, R404.1, R405.1, U401.3 (FB)
GND: C401.2, C402.2, C403.2, C404.2, C406.2, C408.2, C409.2, C410.2, C411.2, C412.2, C413.2, C414.2, C415.2, C416.2, C417.2, C418.2, C419.2, C420.2, C421.2, C422.2, C423.2, C424.2, C425.2, C426.2, C427.2, C428.2, C429.2, C430.2, C431.2, C432.2, C433.2, C434.2, C441.1, J401.8, J401.13, J401.14, J401.20, J401.25, J401.26, J402.1, J403.1, J404.1, JP402.1, R403.2, R404.2, R405.2, U401.2 (GND), U402.4 (GND), U403.23 (GND), U403.33 (GND), U403.48 (GND), U403.65 (EP), U404.4 (VSS), U404.9 (EP), U405.15 (GND), U405.24 (GND), U405.49 (DAP), U406.43 (GND), U407.6 (GND), U407.13 (/EN), Y401.3; also elsewhere on the board
GPIO_23: U407.8 (S3B); also elsewhere on the board
I2C0.SCL: U407.1 (S1B); also elsewhere on the board
I2C0.SDA: U407.4 (S2B); also elsewhere on the board
unnamed: C408.1, R406.2, U403.12 (PD_N)
unnamed: D401.2 (A), L401.2, U401.1 (SW)
unnamed: JP402.2, U405.39 (VOD_SEL)
unnamed: R401.2, U402.5 (2Y), U402.6 (3A), U402.7 (1Y)
unnamed: R402.2, U401.4 (/SHDN), U402.2 (3Y)
SPI1.MISO: J401.21, U403.4 (MISO/IO1); also elsewhere on the board
SPI1.MOSI: J401.19, U403.5 (MOSI/IO0); also elsewhere on the board
SPI1.SCK: J401.17, U403.3 (SCK); also elsewhere on the board
SPI1.SS3: R407.2, U403.6 (CS_N); also elsewhere on the board
iMX8.GPIO5.IO28: U407.9 (S3A); also elsewhere on the board
iMX8.GPIO5.IO29: U407.12 (S4A); also elsewhere on the board
iMX8.I2C3.SCL: U407.16 (S1A); also elsewhere on the board
iMX8.I2C3.SDA: U407.3 (S2A); also elsewhere on the board
iMX8.LVDS0.A0N: U406.18 (9B1); also elsewhere on the board
iMX8.LVDS0.A0P: U406.16 (8B1); also elsewhere on the board
iMX8.LVDS0.A1N: U406.25 (7B1); also elsewhere on the board
iMX8.LVDS0.A1P: U406.26 (6B1); also elsewhere on the board
iMX8.LVDS0.A2N: U406.29 (5B1); also elsewhere on the board
iMX8.LVDS0.A2P: U406.30 (4B1); also elsewhere on the board
iMX8.LVDS0.A3N: U406.38 (1B1); also elsewhere on the board
iMX8.LVDS0.A3P: U406.39 (0B1); also elsewhere on the board
iMX8.LVDS0.CLKN: U406.34 (3B1); also elsewhere on the board
iMX8.LVDS0.CLKP: U406.35 (2B1); also elsewhere on the board
iMX8.PWM1: U402.1 (1A); also elsewhere on the board

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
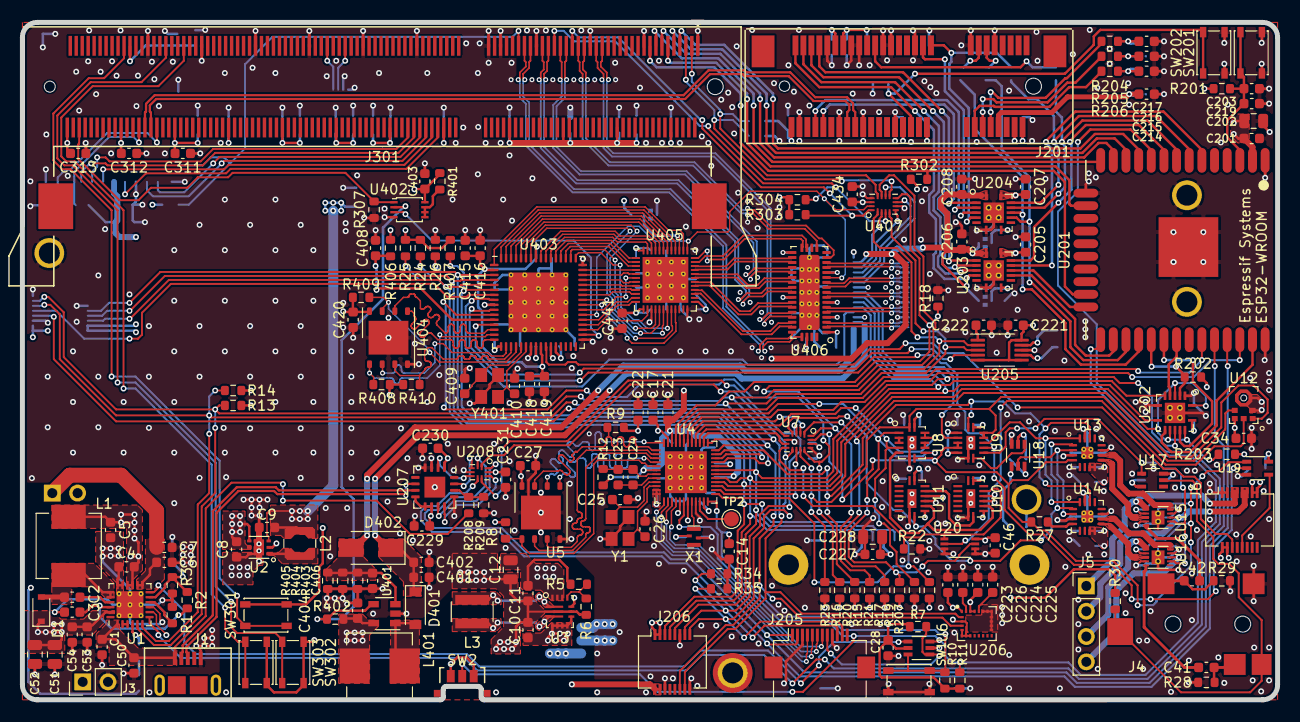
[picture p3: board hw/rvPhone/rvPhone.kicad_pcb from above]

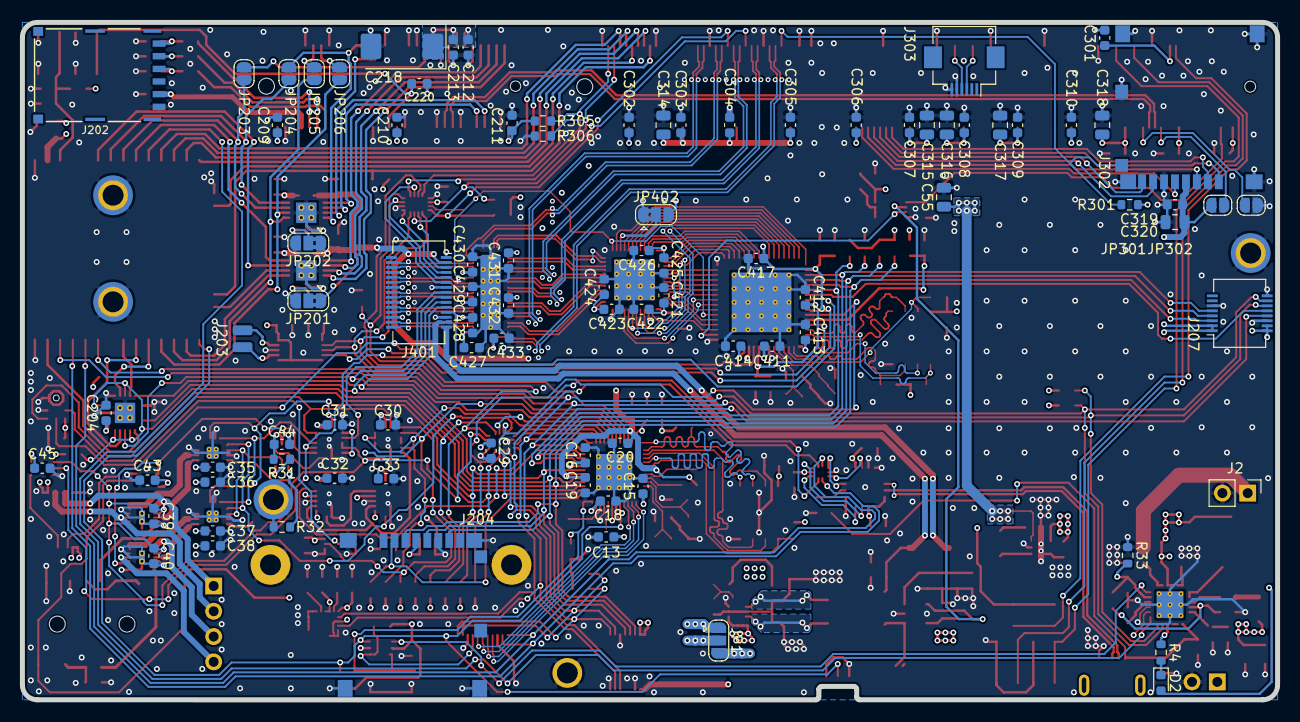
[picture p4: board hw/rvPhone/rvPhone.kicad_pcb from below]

Board: 4 copper layers, 126.0 x 68.0 mm, 283 parts (94 on the bottom side), 258 nets.

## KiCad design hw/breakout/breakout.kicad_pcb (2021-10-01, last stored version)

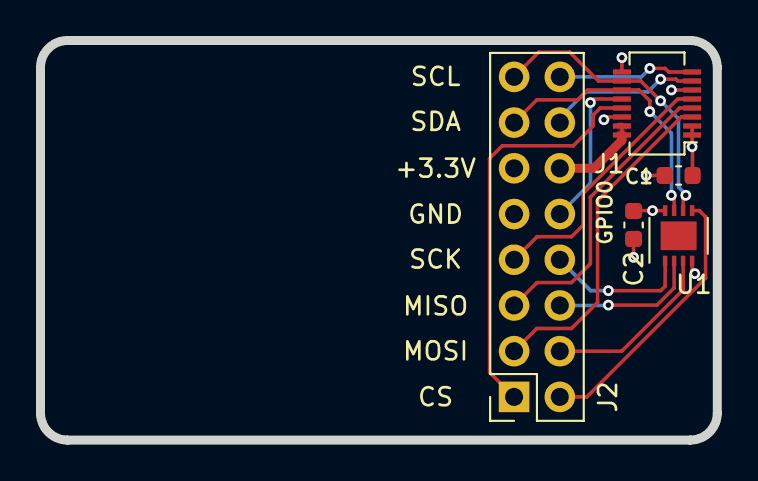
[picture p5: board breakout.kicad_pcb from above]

Board: 4 copper layers, 37.6 x 22.2 mm, 5 parts (0 on the bottom side), 16 nets.

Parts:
C1: 10uF; C_0603_1608Metric
C2: 0.1uF; C_0603_1608Metric
J1: In; Molex_SlimStack_55560-0161_2x08_P0.50mm_Vertical
J2: Out; PinHeader_2x08_P2.54mm_Vertical
U1: PCA9536DP; WSON-8-1EP_3x3mm_P0.5mm_EP1.6x2.0mm

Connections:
+3V3: C1.1, C2.1, J1.1, J1.3, J2.11, U1.8
/GPIO0: J1.10, J2.10
/I2C_SCL: J1.14, J2.15, U1.6
/I2C_SDA: J1.12, J2.13, U1.7
/PCA_IO0: J2.8, U1.1
/PCA_IO1: J2.6, U1.2
/PCA_IO2: J2.4, U1.3
/PCA_IO3: J2.2, U1.5
/SPI_CS: J1.8, J2.1
/SPI_MISO: J1.7, J2.5
/SPI_MOSI: J1.5, J2.3
/SPI_SCK: J1.9, J2.7
/UART_RX: J1.15, J2.16
/UART_TX: J1.13, J2.14
GND: C1.2, C2.2, J1.6, J1.11, J1.16, J2.9, U1.4
VDD: J1.2, J1.4, J2.12

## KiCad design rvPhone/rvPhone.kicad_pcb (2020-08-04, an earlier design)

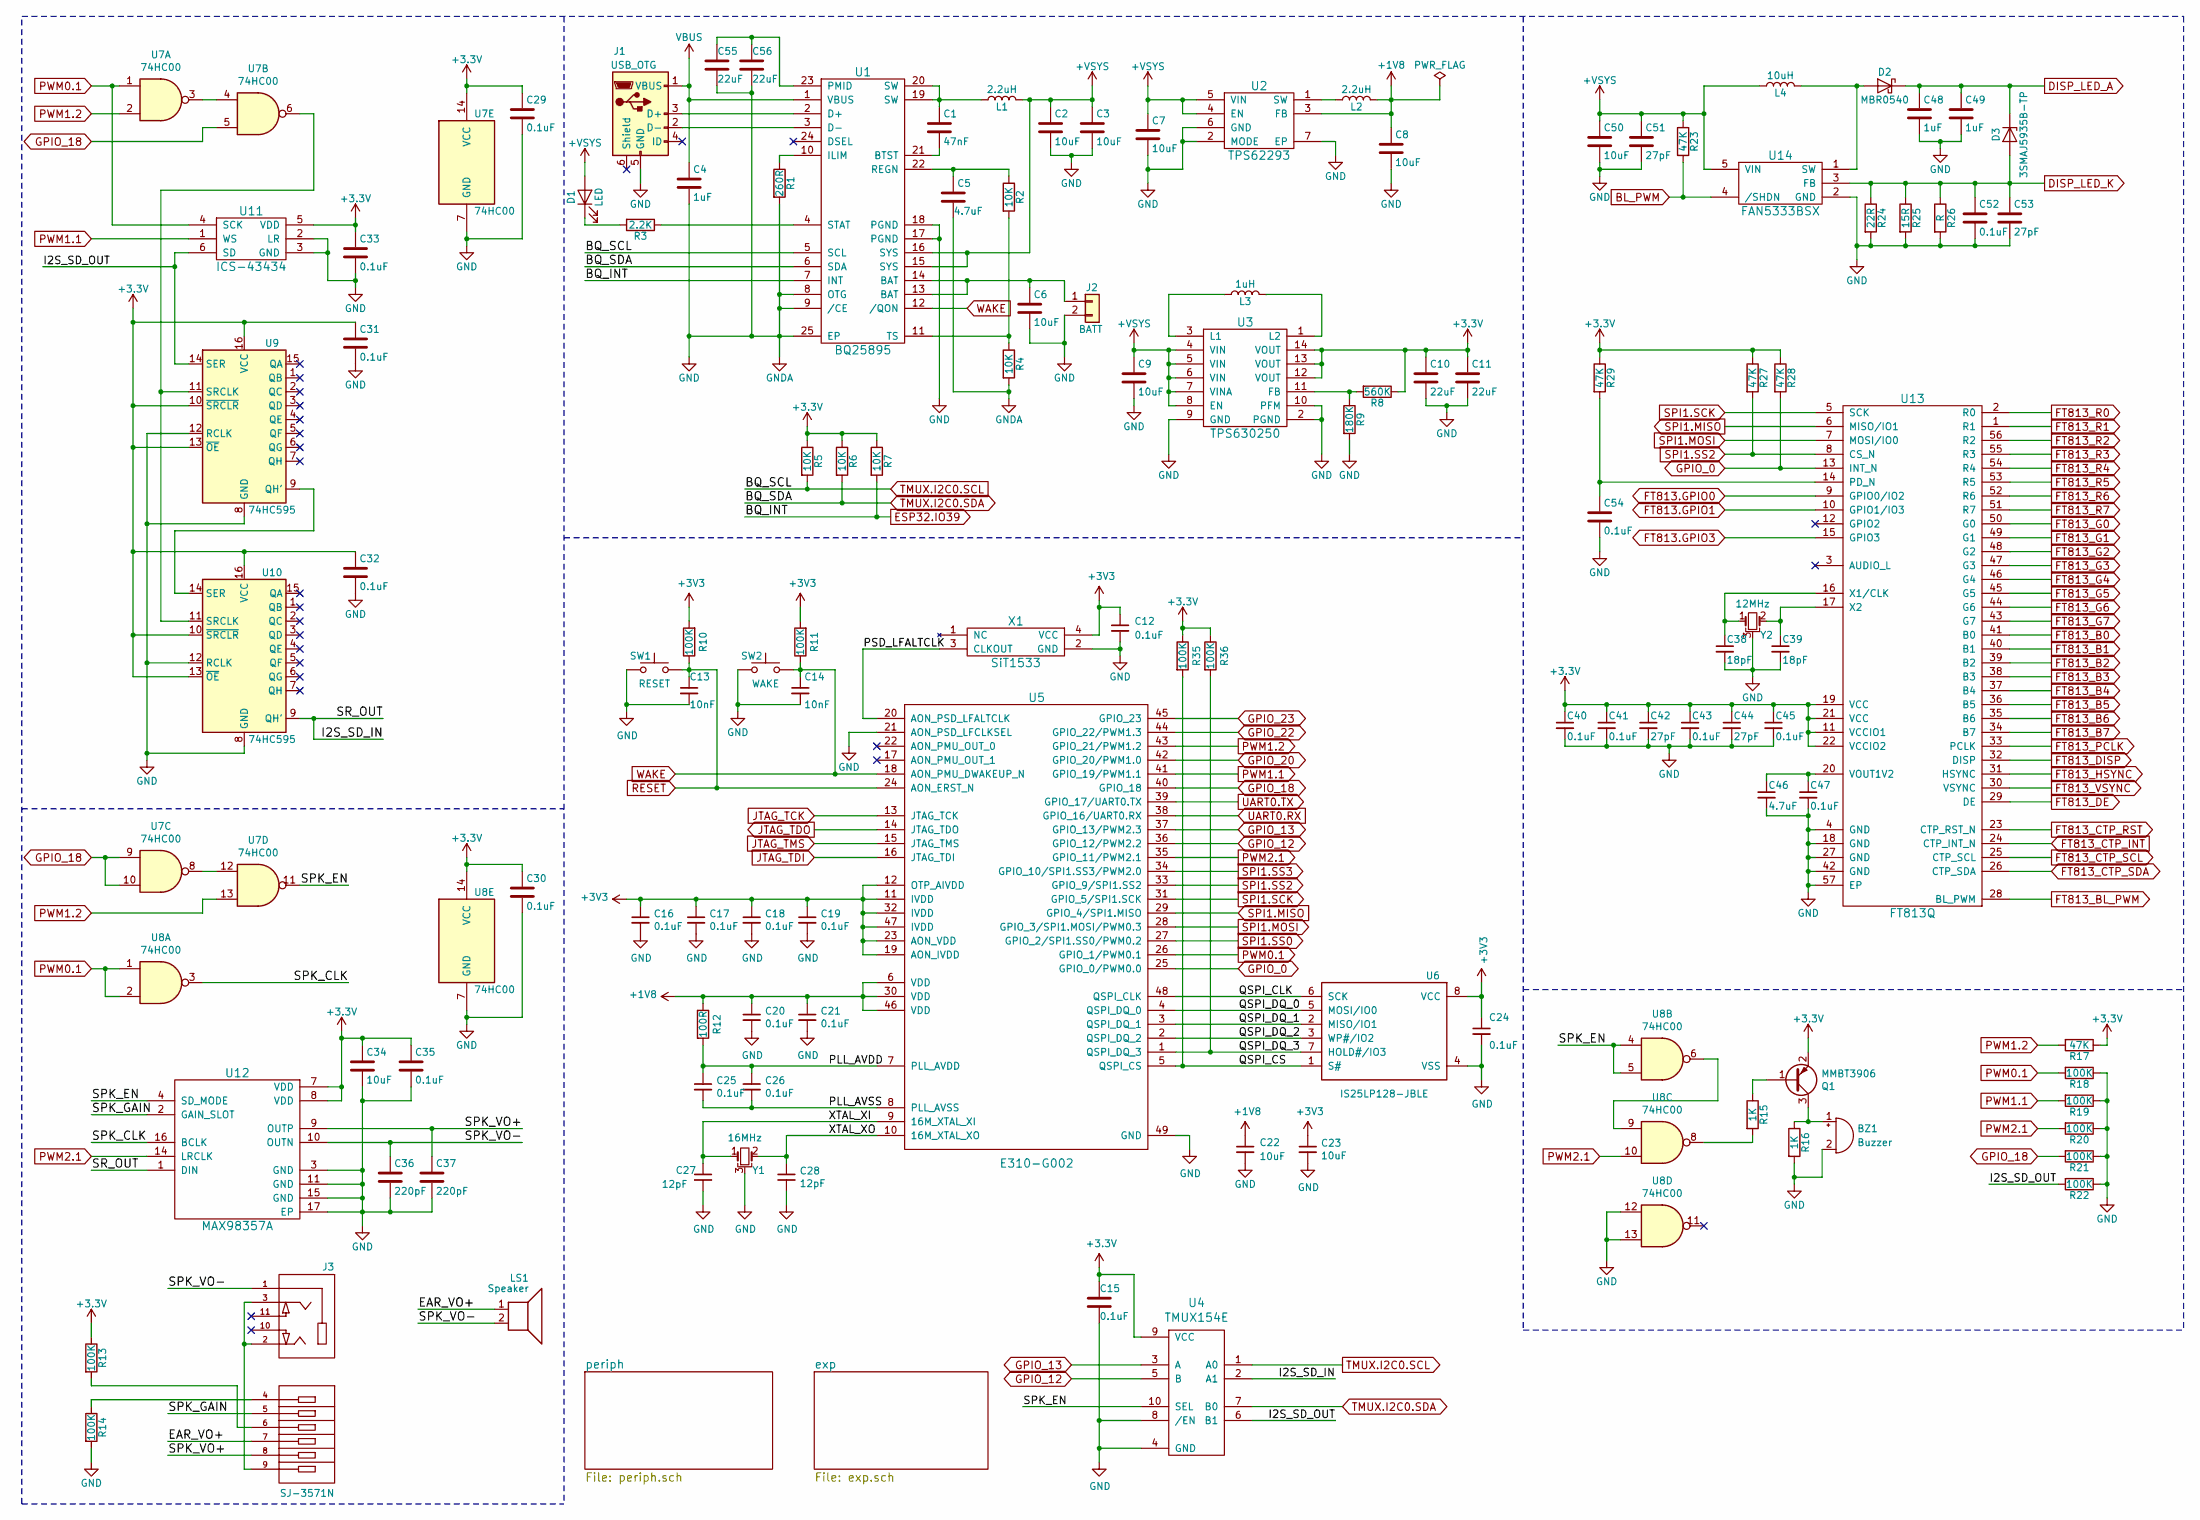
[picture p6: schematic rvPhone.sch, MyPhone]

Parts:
BZ1: Buzzer; Buzzer_12x9.5RM5.0
C1: 47nF; C_0603_1608Metric
C2, C3, C6, C7, C8, C9, C22, C23, C34, C50: 10uF; C_0603_1608Metric
C4, C48, C49: 1uF; C_0603_1608Metric
C5, C46: 4.7uF; C_0603_1608Metric
C10, C11, C55, C56: 22uF; C_0603_1608Metric
C12, C15, C16, C17, C18, C19, C20, C21, C24, C25, C26, C29, C30, C31, C32, C33, C35, C40, C41, C43, C45, C47, C52, C54: 0.1uF; C_0603_1608Metric
C13, C14: 10nF; C_0603_1608Metric
C27, C28: 12pF; C_0603_1608Metric
C36, C37: 220pF; C_0603_1608Metric
C38, C39: 18pF; C_0603_1608Metric
C42, C44, C51, C53: 27pF; C_0603_1608Metric
D1: LED; LED_0603_1608Metric
D2: MBR0540; D_SOD-123
D3: 3SMAJ5935B-TP; D_SMA
J1: USB_OTG; USB_Micro-B
J2: BATT; PinHeader_1x02_P2.00mm_Vertical
J3: SJ-3571N; CUI_SJ-3571N
L1, L2: 2.2uH; L_Coilcraft_LPS3015
L3: 1uH; L_Coilcraft_XAL40
L4: 10uH; L_Murata_LQH66SN
LS1: Speaker; PinHeader_1x02_P1.27mm_Vertical
Q1: MMBT3906; SOT-23
R1: 260R; R_0603_1608Metric
R2, R4, R5, R6, R7: 10K; R_0603_1608Metric
R3: 2.2K; R_0603_1608Metric
R8: 560K; R_0603_1608Metric
R9: 180K; R_0603_1608Metric
R10, R11, R13, R14, R18, R19, R20, R21, R22, R35, R36: 100K; R_0603_1608Metric
R12: 100R; R_0603_1608Metric
R15, R16: 1K; R_0603_1608Metric
R17, R23, R27, R28, R29: 47K; R_0603_1608Metric
R24: 22R; R_0603_1608Metric
R25: 15R; R_0603_1608Metric
R26: R; R_0603_1608Metric
SW1: RESET; Panasonic_EVPBB
SW2: WAKE; Panasonic_EVPAK
U1: BQ25895; Texas_S-PWQFN-N24_EP2.7x2.7mm_ThermalVias
U2: TPS62293; TPS62290
U3: TPS630250
U4: TMUX154E; UQFN-10_1.3x1.8mm_P0.4mm
U5: E310-G002; QFN-48-1EP_6x6mm_P0.4mm_EP4.2x4.2mm_ThermalVias
U6: IS25LP128-JBLE; SOIJ-8_5.3x5.3mm_P1.27mm
U7, U8: 74HC00; 74HC00BQ115
U9, U10: 74HC595; 74HC595BQ115
U11: ICS-43434; TDK_ICS-43434
U12: MAX98357A; TQFN-16-1EP_3x3mm_P0.5mm_EP1.23x1.23mm_ThermalVias
U13: FT813Q; QFN-56-1EP_8x8mm_P0.5mm_EP5.6x5.6mm_ThermalVias
U14: FAN5333BSX; SOT-23-5
X1: SiT1533
Y1: 16MHz; TXC_7M
Y2: 12MHz; TXC_7M

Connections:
+1V8: C8.1, C20.1, C21.1, C22.1, L2.2, R12.1, U2.3 (FB), U5.6 (VDD), U5.30 (VDD), U5.46 (VDD); also elsewhere on the board
+VSYS: C2.1, C3.1, C7.1, C9.1, C50.1, C51.1, D1.2 (A), L1.2, L4.1, R23.1, U1.15 (SYS), U1.16 (SYS), U2.4 (EN), U2.5 (VIN), U3.4 (VIN), U3.5 (VIN), U3.6 (VIN), U3.7 (VINA), U3.8 (EN), U14.5 (VIN); also elsewhere on the board
/EAR_VO+: J3.7, LS1.1
/I2S_SD_IN: U4.2 (A1), U10.9 (QH'), U12.1 (DIN)
/I2S_SD_OUT: R22.2, U4.6 (B1), U9.14 (SER), U11.6 (SD)
/PLL_AVDD: C25.1, C26.1, R12.2, U5.7 (PLL_AVDD)
/PLL_AVSS: C25.2, C26.2, U5.8 (PLL_AVSS)
/PSD_LFALTCLK: U5.20 (AON_PSD_LFALTCLK), X1.3 (CLKOUT)
/QSPI_CLK: U5.48 (QSPI_CLK), U6.6 (SCK)
/QSPI_CS: R35.2, U5.5 (QSPI_CS), U6.1 (S#)
/QSPI_DQ_0: U5.4 (QSPI_DQ_0), U6.5 (MOSI/IO0)
/QSPI_DQ_1: U5.3 (QSPI_DQ_1), U6.2 (MISO/IO1)
/QSPI_DQ_2: U5.2 (QSPI_DQ_2), U6.3 (WP#/IO2)
/QSPI_DQ_3: R36.2, U5.1 (QSPI_DQ_3), U6.7 (HOLD#/IO3)
/SPK_CLK: U8.3, U12.16 (BCLK)
/SPK_EN: U4.10 (SEL), U7.11, U8.4, U8.5, U12.4 (SD_MODE)
/SPK_GAIN: J3.5, U12.2 (GAIN_SLOT)
/SPK_VO+: C37.1, J3.8, U12.9 (OUTP)
/SPK_VO-: C36.1, J3.1, LS1.2, U12.10 (OUTN)
/XTAL_XI: C27.1, U5.9 (16M_XTAL_XI), Y1.1
/XTAL_XO: C28.1, U5.10 (16M_XTAL_XO), Y1.2
BL_PWM: R23.2, U14.4 (/SHDN); also elsewhere on the board
DISP_LED_A: C48.1, C49.1, D2.1 (K), D3.1 (K); also elsewhere on the board
DISP_LED_K: C52.1, C53.1, D3.2 (A), R24.1, R25.1, R26.1, U14.3 (FB); also elsewhere on the board
ESP32.IO39: R7.2, U1.7 (INT); also elsewhere on the board
FT813.GPIO0: U13.9 (GPIO0/IO2); also elsewhere on the board
FT813.GPIO1: U13.10 (GPIO1/IO3); also elsewhere on the board
FT813.GPIO3: U13.15 (GPIO3); also elsewhere on the board
FT813_B0: U13.41 (B0); also elsewhere on the board
FT813_B1: U13.40 (B1); also elsewhere on the board
FT813_B2: U13.39 (B2); also elsewhere on the board
FT813_B3: U13.38 (B3); also elsewhere on the board
FT813_B4: U13.37 (B4); also elsewhere on the board
FT813_B5: U13.36 (B5); also elsewhere on the board
FT813_B6: U13.35 (B6); also elsewhere on the board
FT813_B7: U13.34 (B7); also elsewhere on the board
FT813_BL_PWM: U13.28 (BL_PWM); also elsewhere on the board
FT813_CTP_INT: U13.24 (CTP_INT_N); also elsewhere on the board
FT813_CTP_RST: U13.23 (CTP_RST_N); also elsewhere on the board
FT813_CTP_SCL: U13.25 (CTP_SCL); also elsewhere on the board
FT813_CTP_SDA: U13.26 (CTP_SDA); also elsewhere on the board
FT813_DE: U13.29 (DE); also elsewhere on the board
FT813_DISP: U13.32 (DISP); also elsewhere on the board
FT813_G0: U13.50 (G0); also elsewhere on the board
FT813_G1: U13.49 (G1); also elsewhere on the board
FT813_G2: U13.48 (G2); also elsewhere on the board
FT813_G3: U13.47 (G3); also elsewhere on the board
FT813_G4: U13.46 (G4); also elsewhere on the board
FT813_G5: U13.45 (G5); also elsewhere on the board
FT813_G6: U13.44 (G6); also elsewhere on the board
FT813_G7: U13.43 (G7); also elsewhere on the board
FT813_HSYNC: U13.31 (HSYNC); also elsewhere on the board
FT813_PCLK: U13.33 (PCLK); also elsewhere on the board
FT813_R0: U13.2 (R0); also elsewhere on the board
FT813_R1: U13.1 (R1); also elsewhere on the board
FT813_R2: U13.56 (R2); also elsewhere on the board
FT813_R3: U13.55 (R3); also elsewhere on the board
FT813_R4: U13.54 (R4); also elsewhere on the board
FT813_R5: U13.53 (R5); also elsewhere on the board
FT813_R6: U13.52 (R6); also elsewhere on the board
FT813_R7: U13.51 (R7); also elsewhere on the board
FT813_VSYNC: U13.30 (VSYNC); also elsewhere on the board
GND: BZ1.2 (+), C2.2, C3.2, C4.2, C5.2, C6.2, C7.2, C8.2, C9.2, C10.2, C11.2, C12.2, C13.2, C14.2, C15.2, C16.2, C17.2, C18.2, C19.2, C20.2, C21.2, C22.2, C23.2, C24.2, C27.2, C28.2, C29.2, C30.2, C31.2, C32.2, C33.2, C34.2, C35.2, C36.2, C37.2, C38.2, C39.2, C40.2, C41.2, C42.2, C43.2, C44.2, C45.2, C46.2, C47.2, C48.2, C49.2, C50.2, C51.2, C52.2, C53.2, C54.2, C55.2, C56.2, J1.5 (GND), J2.2, R1.2, R4.2, R9.2, R14.2, R16.2, R18.1, R19.1, R20.1, R21.1, R22.1, R24.2, R25.2, R26.2, SW1.1, SW2.2, U1.8 (OTG), U1.9 (/CE), U1.17 (PGND), U1.18 (PGND), U1.25 (EP), U2.2 (MODE), U2.6 (GND), U2.7 (EP), U3.2 (PGND), U3.9 (GND), U3.10 (PFM), U4.4 (GND), U4.8 (/EN), U5.21 (AON_PSD_LFCLKSEL), U5.49 (GND), U6.4 (VSS), U7.7 (GND), U8.7 (GND), U8.12, U8.13, U9.8 (GND), U9.12 (RCLK), U10.8 (GND), U10.12 (RCLK), U11.2 (LR), U11.3 (GND), U12.3 (GND), U12.11 (GND), U12.15 (GND), U12.17 (EP), U13.4 (GND), U13.18 (GND), U13.27 (GND), U13.42 (GND), U13.57 (EP), U14.2 (GND), X1.2 (GND), Y1.3, Y2.3; also elsewhere on the board
GPIO_0: R28.2, U5.25 (GPIO_0/PWM0.0), U13.13 (INT_N)
GPIO_12: U4.5 (B), U5.36 (GPIO_12/PWM2.2)
GPIO_13: U4.3 (A), U5.37 (GPIO_13/PWM2.3)
GPIO_18: R21.2, U5.40 (GPIO_18), U7.5, U7.9, U7.10
GPIO_20: U5.42 (GPIO_20/PWM1.0); also elsewhere on the board
GPIO_22: U5.44 (GPIO_22/PWM1.3); also elsewhere on the board
GPIO_23: U5.45 (GPIO_23); also elsewhere on the board
JTAG_TCK: U5.13 (JTAG_TCK); also elsewhere on the board
JTAG_TDI: U5.16 (JTAG_TDI); also elsewhere on the board
JTAG_TDO: U5.14 (JTAG_TDO); also elsewhere on the board
JTAG_TMS: U5.15 (JTAG_TMS); also elsewhere on the board
unnamed: BZ1.1 (-), Q1.3 (C), R16.1
unnamed: C1.1, L1.1, U1.19 (SW), U1.20 (SW)
unnamed: C1.2, U1.21 (BTST)
unnamed: C5.1, R2.1, U1.22 (REGN)
unnamed: C6.1, J2.1, U1.13 (BAT), U1.14 (BAT)
unnamed: C38.1, U13.16 (X1/CLK), Y2.1
unnamed: C39.1, U13.17 (X2), Y2.2
unnamed: C46.1, C47.1, U13.20 (VOUT1V2)
unnamed: C54.1, R29.2, U13.14 (PD_N)
unnamed: C55.1, C56.1, U1.23 (PMID)
unnamed: D1.1 (K), R3.2
unnamed: D2.2 (A), L4.2, U14.1 (SW)
unnamed: J1.2 (D-), U1.3 (D-)
unnamed: J1.3 (D+), U1.2 (D+)
unnamed: J3.2, J3.3, J3.9
unnamed: J3.4, R14.1
unnamed: J3.6, R13.2
unnamed: L2.1, U2.1 (SW)
unnamed: L3.1, U3.3 (L1)
unnamed: L3.2, U3.1 (L2)
unnamed: Q1.1 (B), R15.1
unnamed: R1.1, U1.10 (ILIM)
unnamed: R2.2, R4.1, U1.11 (TS)
unnamed: R3.1, U1.4 (STAT)
unnamed: R8.2, R9.1, U3.11 (FB)
unnamed: R15.2, U8.8
unnamed: U7.3, U7.4
unnamed: U7.8, U7.12
unnamed: U8.6, U8.9
unnamed: U7.6, U9.11 (SRCLK), U10.11 (SRCLK)
unnamed: U9.9 (QH'), U10.14 (SER)
PWM0.1: R18.2, U5.26 (GPIO_1/PWM0.1), U7.1, U8.1, U8.2, U11.4 (SCK)
PWM1.1: R19.2, U5.41 (GPIO_19/PWM1.1), U11.1 (WS)
PWM1.2: R17.2, U5.43 (GPIO_21/PWM1.2), U7.2, U7.13
PWM2.1: R20.2, U5.35 (GPIO_11/PWM2.1), U8.10, U12.14 (LRCLK)
RESET: C13.1, R10.1, SW1.2, U5.24 (AON_ERST_N); also elsewhere on the board
SPI1.MISO: U5.29 (GPIO_4/SPI1.MISO), U13.6 (MISO/IO1); also elsewhere on the board
SPI1.MOSI: U5.28 (GPIO_3/SPI1.MOSI/PWM0.3), U13.7 (MOSI/IO0); also elsewhere on the board
SPI1.SCK: U5.31 (GPIO_5/SPI1.SCK), U13.5 (SCK); also elsewhere on the board
SPI1.SS0: U5.27 (GPIO_2/SPI1.SS0/PWM0.2); also elsewhere on the board
SPI1.SS2: R27.2, U5.33 (GPIO_9/SPI1.SS2), U13.8 (CS_N)
SPI1.SS3: U5.34 (GPIO_10/SPI1.SS3/PWM2.0); also elsewhere on the board
TMUX.I2C0.SCL: R5.2, U1.5 (SCL), U4.1 (A0); also elsewhere on the board
TMUX.I2C0.SDA: R6.2, U1.6 (SDA), U4.7 (B0); also elsewhere on the board
UART0.RX: U5.38 (GPIO_16/UART0.RX); also elsewhere on the board
UART0.TX: U5.39 (GPIO_17/UART0.TX); also elsewhere on the board
VBUS: C4.1, J1.1 (VBUS), U1.1 (VBUS)
WAKE: C14.1, R11.1, SW2.1, U1.12 (/QON), U5.18 (AON_PMU_DWAKEUP_N); also elsewhere on the board

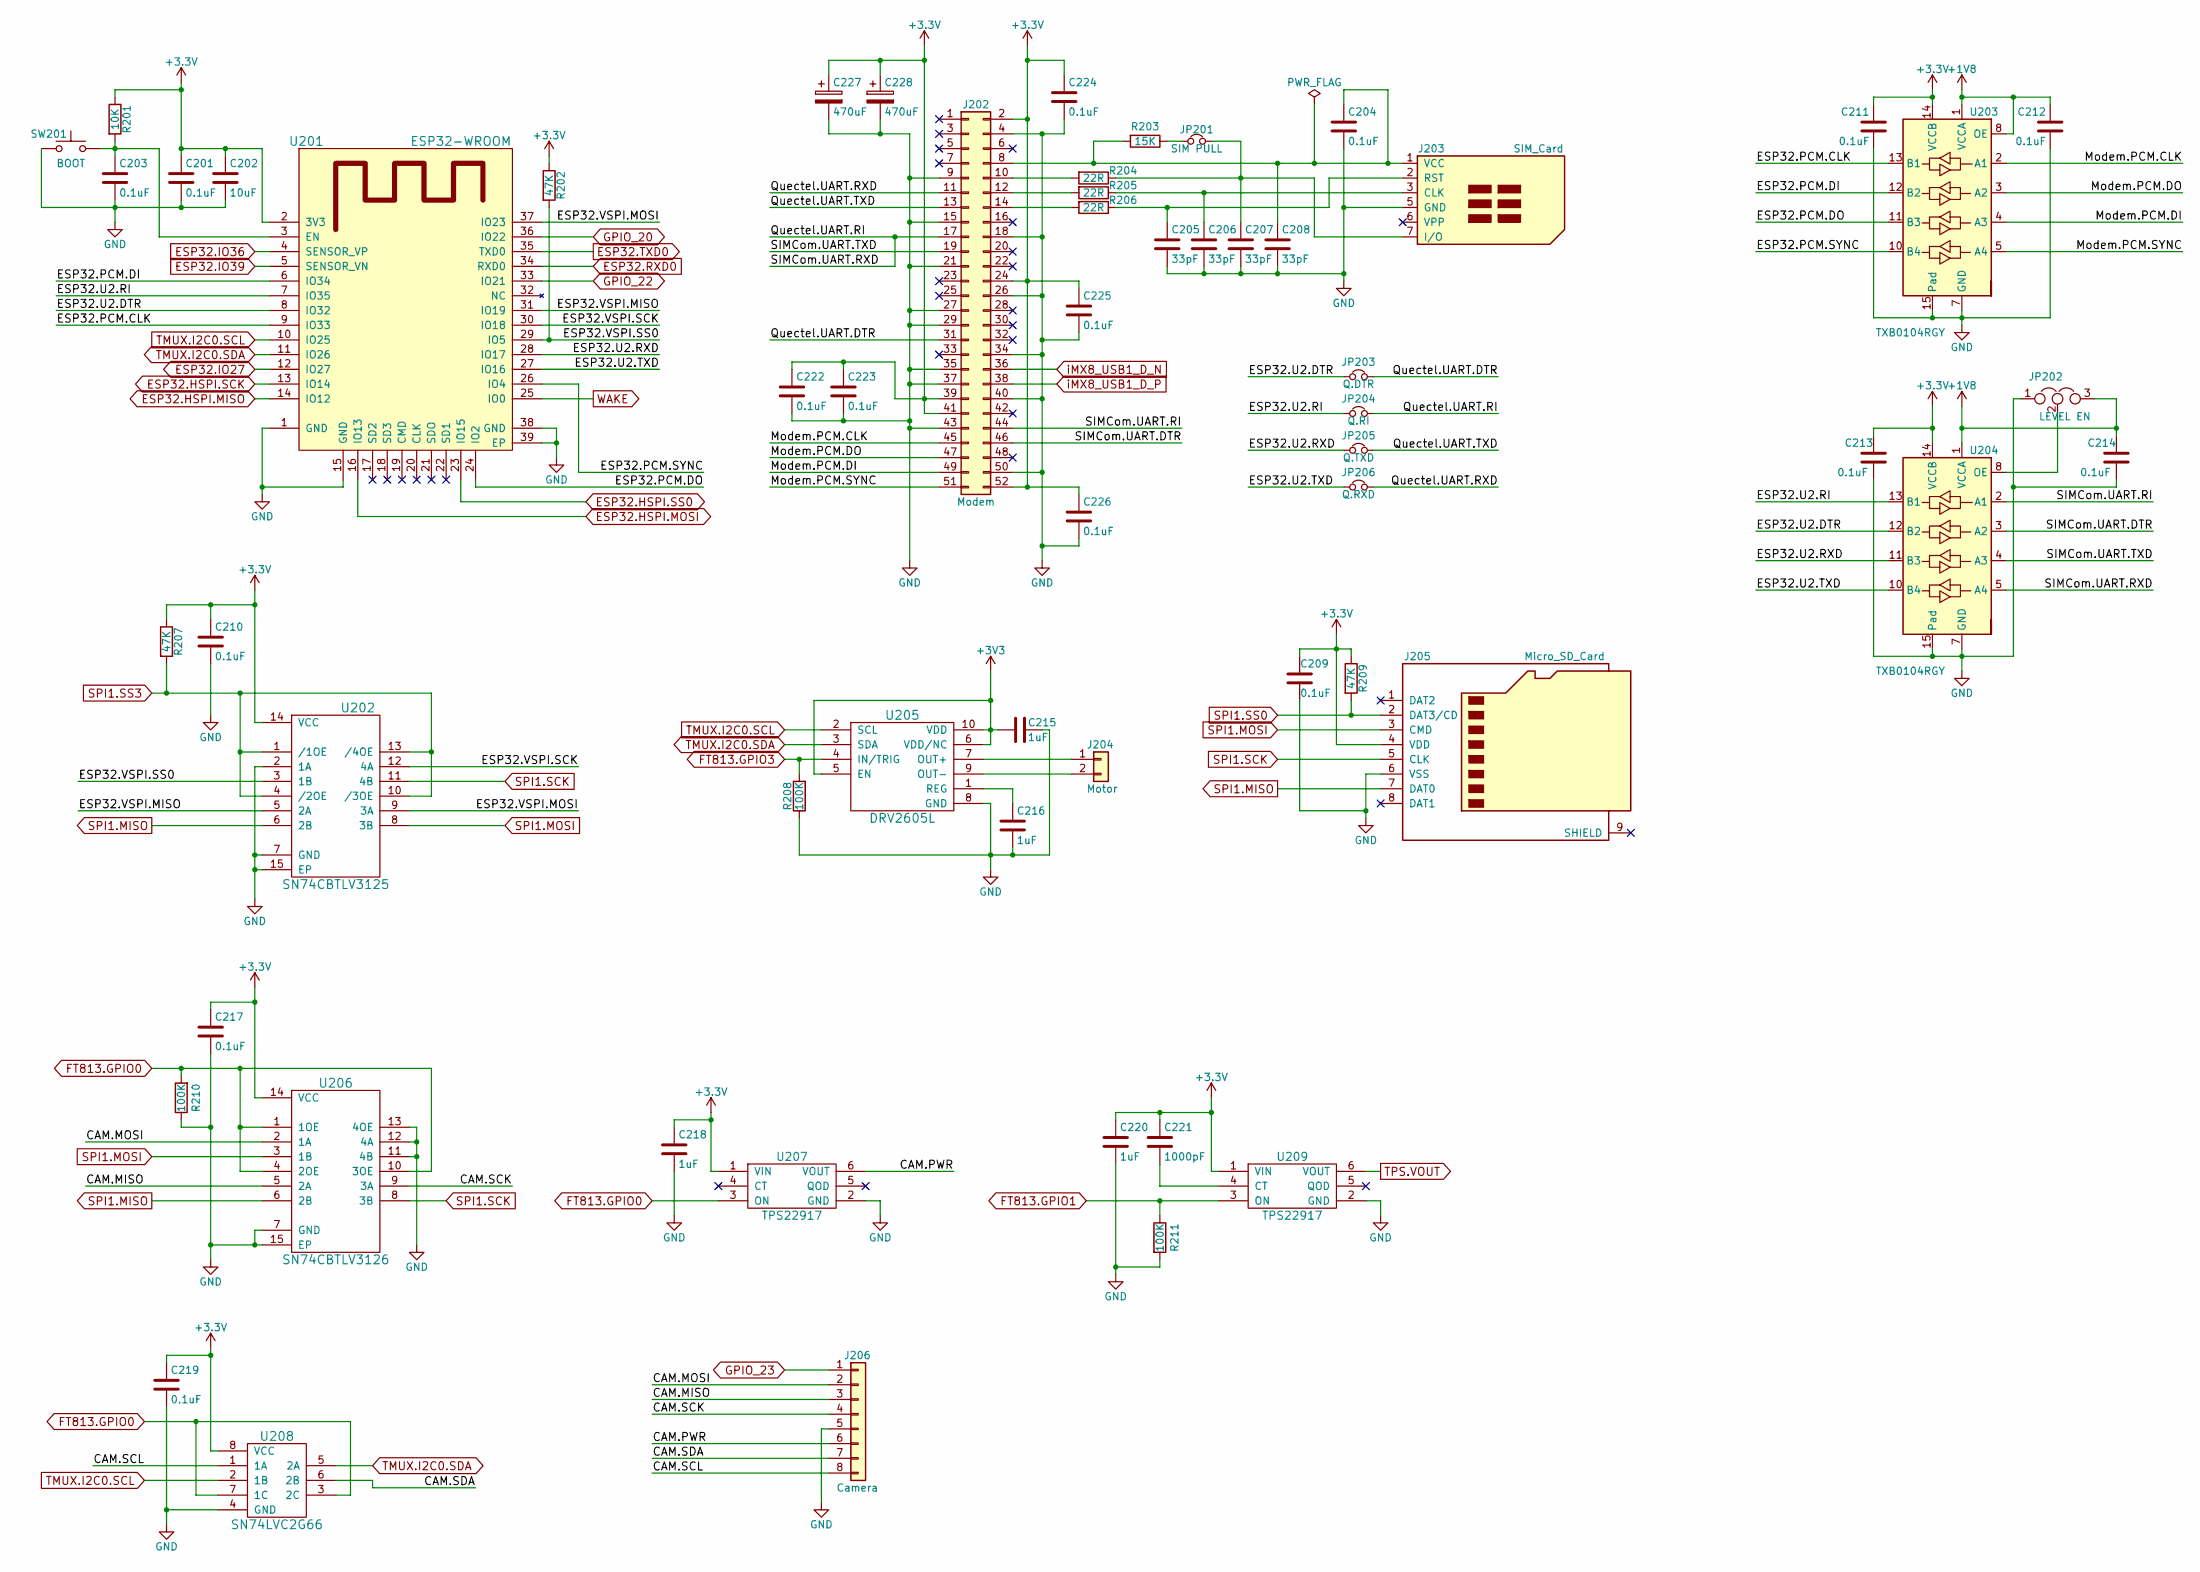
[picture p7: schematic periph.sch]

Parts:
C201, C203, C204, C209, C210, C211, C212, C213, C214, C217, C219, C222, C223, C224, C225, C226: 0.1uF; C_0603_1608Metric
C202: 10uF; C_0603_1608Metric
C205, C206, C207, C208: 33pF; C_0603_1608Metric
C215, C216, C218, C220: 1uF; C_0603_1608Metric
C221: 1000pF; C_0603_1608Metric
C227, C228: 470uF; CP_EIA-3528-21_Kemet-B
J202: Modem; mpcie-socket
J203: SIM_Card; Wurth_NanoSIM-693043020611
J204: Motor; PinHeader_1x02_P1.27mm_Vertical
J205: Micro_SD_Card; MicroSd
J206: Camera; PinHeader_1x08_P2.54mm_Vertical
JP201: SIM PULL; PinHeader_1x02_P1.27mm_Vertical
JP202: LEVEL EN; PinHeader_1x03_P1.27mm_Vertical
JP203: Q.DTR; PinHeader_1x02_P1.27mm_Vertical
JP204: Q.RI; PinHeader_1x02_P1.27mm_Vertical
JP205: Q.TXD; PinHeader_1x02_P1.27mm_Vertical
JP206: Q.RXD; PinHeader_1x02_P1.27mm_Vertical
R201: 10K; R_0603_1608Metric
R202, R207, R209: 47K; R_0603_1608Metric
R203: 15K; R_0603_1608Metric
R204, R205, R206: 22R; R_0603_1608Metric
R208, R210, R211: 100K; R_0603_1608Metric
SW201: BOOT; Panasonic_EVPBB
U201: ESP32-WROOM
U202: SN74CBTLV3125; Texas_S-PVQFN-N14_ThermalVias
U203, U204: TXB0104RGY; Texas_S-PVQFN-N14_ThermalVias
U205: DRV2605L; VSSOP-10_3x3mm_P0.5mm
U206: SN74CBTLV3126; Texas_S-PVQFN-N14_ThermalVias
U207, U209: TPS22917; Texas_R-PDSO-G6
U208: SN74LVC2G66; VSSOP-8_2.4x2.1mm_P0.5mm

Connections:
+1V8: C212.1, C214.1, JP202.3, U203.1 (VCCA), U203.8 (OE), U204.1 (VCCA); also elsewhere on the board
/periph/CAM.MISO: J206.3, U206.5 (2A)
/periph/CAM.MOSI: J206.2, U206.2 (1A)
/periph/CAM.PWR: J206.6, U207.6 (VOUT)
/periph/CAM.SCK: J206.4, U206.9 (3A)
/periph/CAM.SCL: J206.8, U208.1 (1A)
/periph/CAM.SDA: J206.7, U208.6 (2B)
/periph/ESP32.PCM.CLK: U201.9 (IO33), U203.13 (B1)
/periph/ESP32.PCM.DI: U201.6 (IO34), U203.12 (B2)
/periph/ESP32.PCM.DO: U201.24 (IO2), U203.11 (B3)
/periph/ESP32.PCM.SYNC: U201.26 (IO4), U203.10 (B4)
/periph/ESP32.U2.DTR: JP203.1, U201.8 (IO32), U204.12 (B2)
/periph/ESP32.U2.RI: JP204.1, U201.7 (IO35), U204.13 (B1)
/periph/ESP32.U2.RXD: JP205.1, U201.28 (IO17), U204.11 (B3)
/periph/ESP32.U2.TXD: JP206.1, U201.27 (IO16), U204.10 (B4)
/periph/ESP32.VSPI.MISO: U201.31 (IO19), U202.5 (2A)
/periph/ESP32.VSPI.MOSI: U201.37 (IO23), U202.9 (3A)
/periph/ESP32.VSPI.SCK: U201.30 (IO18), U202.12 (4A)
/periph/ESP32.VSPI.SS0: R202.2, U201.29 (IO5), U202.3 (1B)
/periph/Modem.PCM.CLK: J202.45, U203.2 (A1)
/periph/Modem.PCM.DI: J202.49, U203.4 (A3)
/periph/Modem.PCM.DO: J202.47, U203.3 (A2)
/periph/Modem.PCM.SYNC: J202.51, U203.5 (A4)
/periph/Quectel.UART.DTR: J202.31, JP203.2
/periph/Quectel.UART.RI: J202.17, JP204.2, U204.5 (A4)
/periph/Quectel.UART.RXD: J202.11, JP206.2
/periph/Quectel.UART.TXD: J202.13, JP205.2
/periph/SIMCom.UART.DTR: J202.46, U204.3 (A2)
/periph/SIMCom.UART.RI: J202.44, U204.2 (A1)
/periph/SIMCom.UART.TXD: J202.19, U204.4 (A3)
ESP32.HSPI.MISO: U201.14 (IO12); also elsewhere on the board
ESP32.HSPI.MOSI: U201.16 (IO13); also elsewhere on the board
ESP32.HSPI.SCK: U201.13 (IO14); also elsewhere on the board
ESP32.HSPI.SS0: U201.23 (IO15); also elsewhere on the board
ESP32.IO27: U201.12 (IO27); also elsewhere on the board
ESP32.IO36: U201.4 (SENSOR_VP); also elsewhere on the board
ESP32.IO39: U201.5 (SENSOR_VN); also elsewhere on the board
ESP32.RXD0: U201.34 (RXD0); also elsewhere on the board
ESP32.TXD0: U201.35 (TXD0); also elsewhere on the board
FT813.GPIO0: R210.2, U206.1 (1OE), U206.4 (2OE), U206.10 (3OE), U207.3 (ON), U208.3 (2C), U208.7 (1C); also elsewhere on the board
FT813.GPIO1: R211.1, U209.3 (ON); also elsewhere on the board
FT813.GPIO3: R208.2, U205.4 (IN/TRIG); also elsewhere on the board
GND: C201.2, C202.2, C203.2, C204.2, C205.2, C206.2, C207.2, C208.2, C209.2, C210.2, C211.2, C212.2, C213.2, C214.2, C215.1, C216.2, C217.2, C218.2, C219.2, C220.2, C222.2, C223.2, C224.2, C225.2, C226.2, C227.2, C228.2, J202.4, J202.9, J202.15, J202.18, J202.21, J202.26, J202.27, J202.29, J202.34, J202.35, J202.37, J202.40, J202.43, J202.50, J203.5 (GND), J205.6 (VSS), J206.5, JP202.1, R208.1, R210.1, R211.2, SW201.2, U201.1 (GND), U201.15 (GND), U201.38 (GND), U201.39 (EP), U202.2 (1A), U202.7 (GND), U202.15 (EP), U203.7 (GND), U203.15 (Pad), U204.7 (GND), U204.15 (Pad), U205.8 (GND), U206.7 (GND), U206.11 (4B), U206.12 (4A), U206.13 (4OE), U206.15 (EP), U207.2 (GND), U208.4 (GND), U209.2 (GND); also elsewhere on the board
GPIO_20: U201.36 (IO22); also elsewhere on the board
GPIO_22: U201.33 (IO21); also elsewhere on the board
GPIO_23: J206.1; also elsewhere on the board
unnamed: C203.1, R201.2, SW201.1, U201.3 (EN)
unnamed: C204.1, C208.1, J202.8, J203.1 (VCC), R203.2
unnamed: C205.1, J203.2 (RST), R206.1
unnamed: C206.1, J203.3 (CLK), R205.1
unnamed: C207.1, J203.7 (I/O), JP201.2, R204.1
unnamed: C216.1, U205.1 (REG)
unnamed: C221.2, U209.4 (CT)
unnamed: J202.10, R204.2
unnamed: J202.12, R205.2
unnamed: J202.14, R206.2
unnamed: J204.1, U205.7 (OUT+)
unnamed: J204.2, U205.9 (OUT-)
unnamed: JP201.1, R203.1
unnamed: JP202.2, U204.8 (OE)
SPI1.MISO: J205.7 (DAT0), U202.6 (2B), U206.6 (2B); also elsewhere on the board
SPI1.MOSI: J205.3 (CMD), U202.8 (3B), U206.3 (1B); also elsewhere on the board
SPI1.SCK: J205.5 (CLK), U202.11 (4B), U206.8 (3B); also elsewhere on the board
SPI1.SS0: J205.2 (DAT3/CD), R209.2; also elsewhere on the board
SPI1.SS3: R207.2, U202.1 (/1OE), U202.4 (/2OE), U202.10 (/3OE), U202.13 (/4OE); also elsewhere on the board
TMUX.I2C0.SCL: U201.10 (IO25), U205.2 (SCL), U208.2 (1B); also elsewhere on the board
TMUX.I2C0.SDA: U201.11 (IO26), U205.3 (SDA), U208.5 (2A); also elsewhere on the board
TPS.VOUT: U209.6 (VOUT); also elsewhere on the board
WAKE: U201.25 (IO0); also elsewhere on the board
iMX8_USB1_D_N: J202.36; also elsewhere on the board
iMX8_USB1_D_P: J202.38; also elsewhere on the board

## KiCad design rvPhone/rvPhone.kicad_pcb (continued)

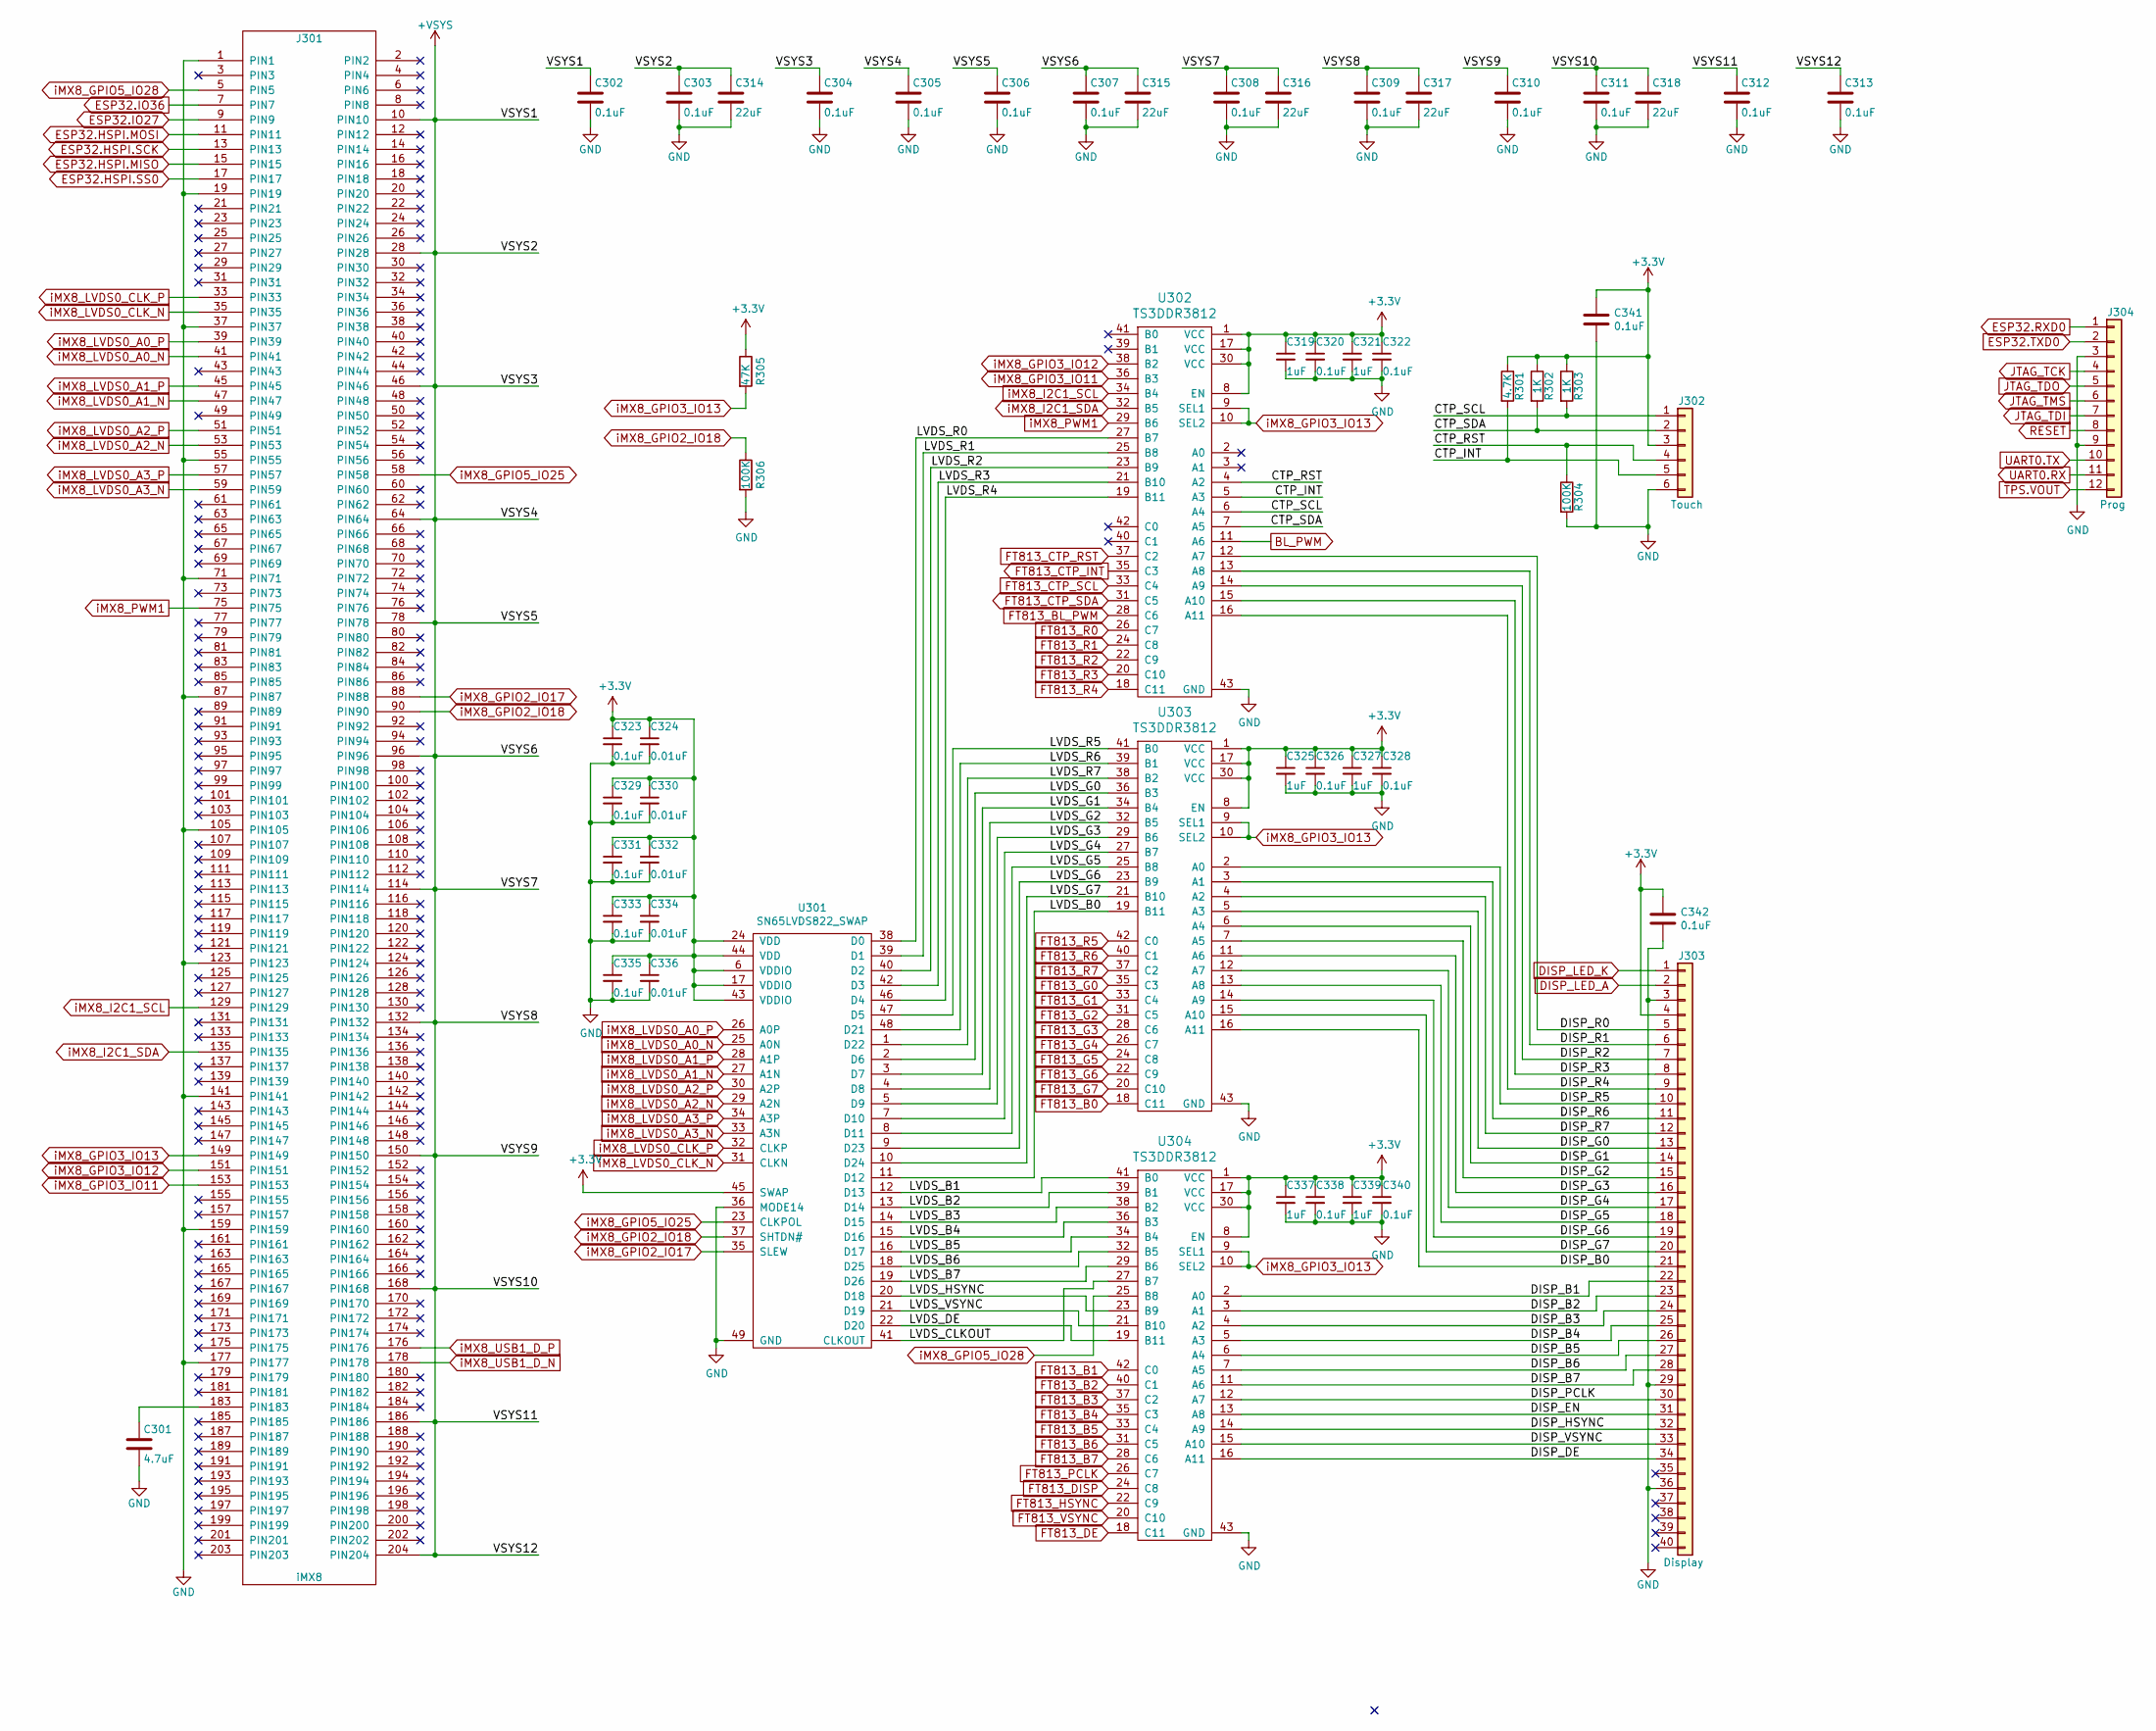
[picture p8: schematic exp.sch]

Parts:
C301: 4.7uF; C_0603_1608Metric
C302, C303, C304, C305, C306, C307, C308, C309, C310, C311, C312, C313, C320, C322, C323, C326, C328, C329, C331, C333, C335, C338, C340, C341, C342: 0.1uF; C_0603_1608Metric
C314, C315, C316, C317, C318: 22uF; C_0603_1608Metric
C319, C321, C325, C327, C337, C339: 1uF; C_0603_1608Metric
C324, C330, C332, C334, C336: 0.01uF; C_0603_1608Metric
J301: iMX8; Socket_SODIMM_DDR3_TE_2013289
J302: Touch; Hirose_FH12-6S-0.5SH_1x06-1MP_P0.50mm_Horizontal
J303: Display; Hirose_FH12-40S-0.5SH_1x40-1MP_P0.50mm_Horizontal
J304: Prog; Hirose_FH12-12S-0.5SH_1x12-1MP_P0.50mm_Horizontal
R301: 4.7K; R_0603_1608Metric
R302, R303: 1K; R_0603_1608Metric
R304, R306: 100K; R_0603_1608Metric
R305: 47K; R_0603_1608Metric
U301: SN65LVDS822_SWAP; QFN-48-1EP_7x7mm_P0.5mm_EP5.15x5.15mm_ThermalVias
U302, U303, U304: TS3DDR3812; Texas_R-PWQFN-N42

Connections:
+VSYS: C302.1, C303.1, C304.1, C305.1, C306.1, C307.1, C308.1, C309.1, C310.1, C311.1, C312.1, C313.1, C314.1, C315.1, C316.1, C317.1, C318.1, J301.10 (PIN10), J301.28 (PIN28), J301.46 (PIN46), J301.64 (PIN64), J301.78 (PIN78), J301.96 (PIN96), J301.114 (PIN114), J301.132 (PIN132), J301.150 (PIN150), J301.168 (PIN168), J301.186 (PIN186), J301.204 (PIN204); also elsewhere on the board
/exp/CTP_INT: J302.5, R301.2, U302.5 (A3)
/exp/CTP_RST: J302.4, R304.1, U302.4 (A2)
/exp/CTP_SCL: J302.1, R303.2, U302.6 (A4)
/exp/CTP_SDA: J302.2, R302.2, U302.7 (A5)
/exp/DISP_B0: J303.21, U303.16 (A11)
/exp/DISP_B1: J303.22, U304.2 (A0)
/exp/DISP_B2: J303.23, U304.3 (A1)
/exp/DISP_B3: J303.24, U304.4 (A2)
/exp/DISP_B4: J303.25, U304.5 (A3)
/exp/DISP_B5: J303.26, U304.6 (A4)
/exp/DISP_B6: J303.27, U304.7 (A5)
/exp/DISP_B7: J303.28, U304.11 (A6)
/exp/DISP_DE: J303.34, U304.16 (A11)
/exp/DISP_EN: J303.31, U304.13 (A8)
/exp/DISP_G0: J303.13, U303.5 (A3)
/exp/DISP_G1: J303.14, U303.6 (A4)
/exp/DISP_G2: J303.15, U303.7 (A5)
/exp/DISP_G3: J303.16, U303.11 (A6)
/exp/DISP_G4: J303.17, U303.12 (A7)
/exp/DISP_G5: J303.18, U303.13 (A8)
/exp/DISP_G6: J303.19, U303.14 (A9)
/exp/DISP_G7: J303.20, U303.15 (A10)
/exp/DISP_HSYNC: J303.32, U304.14 (A9)
/exp/DISP_PCLK: J303.30, U304.12 (A7)
/exp/DISP_R0: J303.5, U302.12 (A7)
/exp/DISP_R1: J303.6, U302.13 (A8)
/exp/DISP_R2: J303.7, U302.14 (A9)
/exp/DISP_R3: J303.8, U302.15 (A10)
/exp/DISP_R4: J303.9, U302.16 (A11)
/exp/DISP_R5: J303.10, U303.2 (A0)
/exp/DISP_R6: J303.11, U303.3 (A1)
/exp/DISP_R7: J303.12, U303.4 (A2)
/exp/DISP_VSYNC: J303.33, U304.15 (A10)
/exp/LVDS_B0: U301.11 (D12), U303.19 (B11)
/exp/LVDS_B1: U301.12 (D13), U304.41 (B0)
/exp/LVDS_B2: U301.13 (D14), U304.39 (B1)
/exp/LVDS_B3: U301.14 (D15), U304.38 (B2)
/exp/LVDS_B4: U301.15 (D16), U304.36 (B3)
/exp/LVDS_B5: U301.16 (D17), U304.34 (B4)
/exp/LVDS_B6: U301.18 (D25), U304.32 (B5)
/exp/LVDS_B7: U301.19 (D26), U304.29 (B6)
/exp/LVDS_CLKOUT: U301.41 (CLKOUT), U304.27 (B7)
/exp/LVDS_DE: U301.22 (D20), U304.19 (B11)
/exp/LVDS_G0: U301.2 (D6), U303.36 (B3)
/exp/LVDS_G1: U301.3 (D7), U303.34 (B4)
/exp/LVDS_G2: U301.4 (D8), U303.32 (B5)
/exp/LVDS_G3: U301.5 (D9), U303.29 (B6)
/exp/LVDS_G4: U301.7 (D10), U303.27 (B7)
/exp/LVDS_G5: U301.8 (D11), U303.25 (B8)
/exp/LVDS_G6: U301.9 (D23), U303.23 (B9)
/exp/LVDS_G7: U301.10 (D24), U303.21 (B10)
/exp/LVDS_HSYNC: U301.20 (D18), U304.23 (B9)
/exp/LVDS_R0: U301.38 (D0), U302.27 (B7)
/exp/LVDS_R1: U301.39 (D1), U302.25 (B8)
/exp/LVDS_R2: U301.40 (D2), U302.23 (B9)
/exp/LVDS_R3: U301.42 (D3), U302.21 (B10)
/exp/LVDS_R4: U301.46 (D4), U302.19 (B11)
/exp/LVDS_R5: U301.47 (D5), U303.41 (B0)
/exp/LVDS_R6: U301.48 (D21), U303.39 (B1)
/exp/LVDS_R7: U301.1 (D22), U303.38 (B2)
/exp/LVDS_VSYNC: U301.21 (D19), U304.21 (B10)
BL_PWM: U302.11 (A6); also elsewhere on the board
DISP_LED_A: J303.2; also elsewhere on the board
DISP_LED_K: J303.1; also elsewhere on the board
ESP32.HSPI.MISO: J301.15 (PIN15); also elsewhere on the board
ESP32.HSPI.MOSI: J301.11 (PIN11); also elsewhere on the board
ESP32.HSPI.SCK: J301.13 (PIN13); also elsewhere on the board
ESP32.HSPI.SS0: J301.17 (PIN17); also elsewhere on the board
ESP32.IO27: J301.9 (PIN9); also elsewhere on the board
ESP32.IO36: J301.7 (PIN7); also elsewhere on the board
ESP32.RXD0: J304.1; also elsewhere on the board
ESP32.TXD0: J304.2; also elsewhere on the board
FT813_B0: U303.18 (C11); also elsewhere on the board
FT813_B1: U304.42 (C0); also elsewhere on the board
FT813_B2: U304.40 (C1); also elsewhere on the board
FT813_B3: U304.37 (C2); also elsewhere on the board
FT813_B4: U304.35 (C3); also elsewhere on the board
FT813_B5: U304.33 (C4); also elsewhere on the board
FT813_B6: U304.31 (C5); also elsewhere on the board
FT813_B7: U304.28 (C6); also elsewhere on the board
FT813_BL_PWM: U302.28 (C6); also elsewhere on the board
FT813_CTP_INT: U302.35 (C3); also elsewhere on the board
FT813_CTP_RST: U302.37 (C2); also elsewhere on the board
FT813_CTP_SCL: U302.33 (C4); also elsewhere on the board
FT813_CTP_SDA: U302.31 (C5); also elsewhere on the board
FT813_DE: U304.18 (C11); also elsewhere on the board
FT813_DISP: U304.24 (C8); also elsewhere on the board
FT813_G0: U303.35 (C3); also elsewhere on the board
FT813_G1: U303.33 (C4); also elsewhere on the board
FT813_G2: U303.31 (C5); also elsewhere on the board
FT813_G3: U303.28 (C6); also elsewhere on the board
FT813_G4: U303.26 (C7); also elsewhere on the board
FT813_G5: U303.24 (C8); also elsewhere on the board
FT813_G6: U303.22 (C9); also elsewhere on the board
FT813_G7: U303.20 (C10); also elsewhere on the board
FT813_HSYNC: U304.22 (C9); also elsewhere on the board
FT813_PCLK: U304.26 (C7); also elsewhere on the board
FT813_R0: U302.26 (C7); also elsewhere on the board
FT813_R1: U302.24 (C8); also elsewhere on the board
FT813_R2: U302.22 (C9); also elsewhere on the board
FT813_R3: U302.20 (C10); also elsewhere on the board
FT813_R4: U302.18 (C11); also elsewhere on the board
FT813_R5: U303.42 (C0); also elsewhere on the board
FT813_R6: U303.40 (C1); also elsewhere on the board
FT813_R7: U303.37 (C2); also elsewhere on the board
FT813_VSYNC: U304.20 (C10); also elsewhere on the board
GND: C301.2, C302.2, C303.2, C304.2, C305.2, C306.2, C307.2, C308.2, C309.2, C310.2, C311.2, C312.2, C313.2, C314.2, C315.2, C316.2, C317.2, C318.2, C319.2, C320.2, C321.2, C322.2, C323.2, C324.2, C325.2, C326.2, C327.2, C328.2, C329.2, C330.2, C331.2, C332.2, C333.2, C334.2, C335.2, C336.2, C337.2, C338.2, C339.2, C340.2, C341.2, C342.2, J301.1 (PIN1), J301.19 (PIN19), J301.37 (PIN37), J301.55 (PIN55), J301.71 (PIN71), J301.87 (PIN87), J301.105 (PIN105), J301.123 (PIN123), J301.141 (PIN141), J301.159 (PIN159), J301.177 (PIN177), J302.6, J303.3, J303.29, J303.36, J304.3, J304.9, R304.2, R306.2, U301.36 (MODE14), U301.49 (GND), U302.43 (GND), U303.43 (GND), U304.43 (GND); also elsewhere on the board
JTAG_TCK: J304.4; also elsewhere on the board
JTAG_TDI: J304.7; also elsewhere on the board
JTAG_TDO: J304.5; also elsewhere on the board
JTAG_TMS: J304.6; also elsewhere on the board
unnamed: C301.1, J301.183 (PIN183)
RESET: J304.8; also elsewhere on the board
TPS.VOUT: J304.12; also elsewhere on the board
UART0.RX: J304.11; also elsewhere on the board
UART0.TX: J304.10; also elsewhere on the board
iMX8_GPIO2_IO17: J301.88 (PIN88), U301.35 (SLEW)
iMX8_GPIO2_IO18: J301.90 (PIN90), R306.1, U301.37 (SHTDN#)
iMX8_GPIO3_IO11: J301.153 (PIN153), U302.36 (B3)
iMX8_GPIO3_IO12: J301.151 (PIN151), U302.38 (B2)
iMX8_GPIO3_IO13: J301.149 (PIN149), R305.2, U302.9 (SEL1), U302.10 (SEL2), U303.9 (SEL1), U303.10 (SEL2), U304.9 (SEL1), U304.10 (SEL2)
iMX8_GPIO5_IO25: J301.58 (PIN58), U301.23 (CLKPOL)
iMX8_GPIO5_IO28: J301.5 (PIN5), U304.25 (B8)
iMX8_I2C1_SCL: J301.129 (PIN129), U302.34 (B4)
iMX8_I2C1_SDA: J301.135 (PIN135), U302.32 (B5)
iMX8_LVDS0_A0_N: J301.41 (PIN41), U301.25 (A0N)
iMX8_LVDS0_A0_P: J301.39 (PIN39), U301.26 (A0P)
iMX8_LVDS0_A1_N: J301.47 (PIN47), U301.27 (A1N)
iMX8_LVDS0_A1_P: J301.45 (PIN45), U301.28 (A1P)
iMX8_LVDS0_A2_N: J301.53 (PIN53), U301.29 (A2N)
iMX8_LVDS0_A2_P: J301.51 (PIN51), U301.30 (A2P)
iMX8_LVDS0_A3_N: J301.59 (PIN59), U301.33 (A3N)
iMX8_LVDS0_A3_P: J301.57 (PIN57), U301.34 (A3P)
iMX8_LVDS0_CLK_N: J301.35 (PIN35), U301.31 (CLKN)
iMX8_LVDS0_CLK_P: J301.33 (PIN33), U301.32 (CLKP)
iMX8_PWM1: J301.75 (PIN75), U302.29 (B6)
iMX8_USB1_D_N: J301.178 (PIN178); also elsewhere on the board
iMX8_USB1_D_P: J301.176 (PIN176); also elsewhere on the board

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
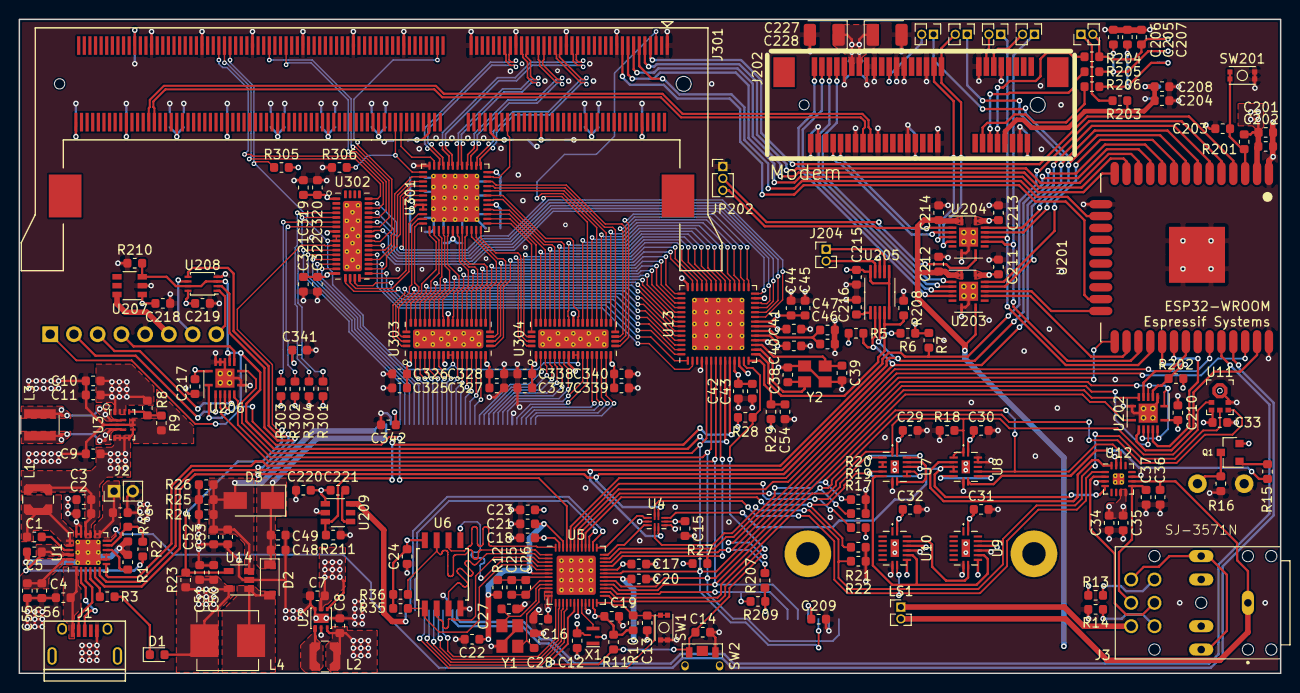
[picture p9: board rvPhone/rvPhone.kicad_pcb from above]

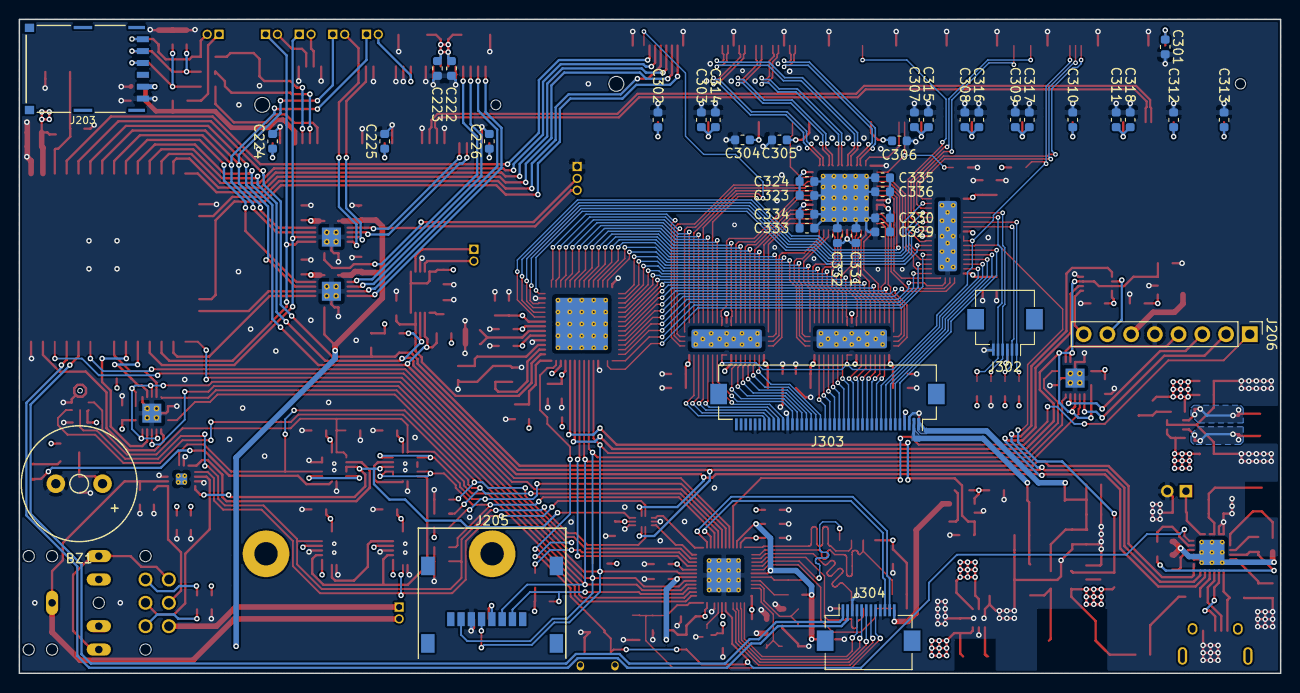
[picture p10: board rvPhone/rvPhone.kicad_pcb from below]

Board: 4 copper layers, 135.0 x 70.0 mm, 235 parts (40 on the bottom side), 259 nets.

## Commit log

2017-06-06 voip test case added
2017-08-04 fixed threads; fixed conn_close
2017-08-18 timer fixed; rbuf almost implemented
2017-08-19 timer improved; rbuf finally implemented
2017-09-09 video test prints to stderr
2018-01-20 foxed esp32 semaphore bug
2018-01-22 fixed esp32 driver: moved xSemaphoreTake from ISR
2018-03-14 i2s driver added; new amd trap entry vector added
2018-03-15 fixed debug print; removed config.h
2018-03-15 fixed debug print
2018-03-17 pwm scaling for i2s sck line added
2018-03-21 fixed net driver; added asm version of spi handlers
2018-03-21 added missing headers for asm version of spi handlers
2018-03-22 spi exchange handler simplified; net test pass with asm spi handlers
2018-03-23 fixed asm rts spi handler; added sample rate to i2s init; refactored
2018-03-27 fixed wm param for spi; added cond compile for spi handlers in asm; refactored i2s
2018-07-29 pin numbers fixed
2019-01-09 i2s speaker driver added
2019-04-09 removed reprecated footprints directory
2019-04-09 added project cache lib
    [exp.sch, myPhone.sch, periph.sch]
2019-05-06 pin numbers cleanup
2019-07-26 fixed audio pins for phone board
2019-08-12 upgrade to kicad 5; fixed footprints
    [exp.sch, myPhone.kicad_pcb, myPhone.sch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]
2019-08-30 REV1 board
    [exp.sch, myPhone.kicad_pcb, myPhone.sch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]
2019-08-30 stub drivers added
2019-09-18 display switch pull resistors added
    [exp.sch, myPhone.kicad_pcb, myPhone.sch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]
2019-09-19 fixed battery charger; added i2c switch for fe310; swapped pwm1/pwm2 for mic/spk
    [exp.sch, myPhone.kicad_pcb, myPhone.sch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]
2019-09-24 solder mask clearance/width fixed; REV1 board
    [myPhone.kicad_pcb]
2019-10-08 fixed audio and spi pins for board REV1
2019-10-15 event handler flags per evt subtype timer has evt subtypes i2s refactor i2s has spk event i2s fixed intr handler audio buf push msgq fixed get message
2019-10-15 fixed timer set according to new timer subtypes spec
2019-10-15 timer bugfix
2019-10-18 added spi driver
2019-10-18 fixed interrupt priority defs
2019-10-18 spi: added wait condition; fixed init proc
2019-10-19 network sockets added
2019-11-25 timer added sleep, timer_set gets msec
2019-11-25 eos timer_set gets msec
2019-11-26 spi refacrot and bugfix
2019-11-27 spi/net integration bugfix
2019-12-04 esp32 refactoring
2019-12-04 esp32: added sock interface
2019-12-07 added net_alloc; fixed cell modem driver
2019-12-07 addded uart driver and cell stub driver
2019-12-08 fixed uart data relay bug; fixed all xCreateTask to use new macros for stack size; fixed err type for msgq;
2019-12-12 fixed bug in i2s spk driver
2019-12-13 fixed and verified audio driver
2019-12-25 eve touch driver added; text box updated;
2020-02-19 eve long press/double tap/inertial scroll spi flush bugfix resolved dependecies: spi -> net; event -> net renamed various handlers
2020-02-26 spi driver func rename/optimization
2020-02-26 net driver func rename
2020-02-26 eve etype refactor; eve text track with inert bugfix
2020-02-26 cell uart/pcm fixes
2020-03-11 timer fix
2020-03-11 eve refactor: keyboard scale param; track extended; oscillator extended tracker
2020-05-06 at cmd processing; pppos driver
2020-05-09 added sleep/wake for modem; fixed ppp driver API
2020-05-09 fixed wifi driver
2020-05-09 wifi driver fix
2020-05-17 power management implemented; net protocol change
2020-05-17 power management fix
2020-05-23 eve power amanger fix
2020-05-23 esp32 deep sleep implemented
2020-05-26 added license
    [myPhone.kicad_pcb]
2020-08-04 renamed to rvPhone
    [exp.sch, periph.sch, rvPhone.kicad_pcb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]
2020-08-04 hw moved
    [exp.sch, periph.sch, rvPhone.kicad_pcb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]
2020-08-07 net driver: removed obsolete flags; urc process simplefied; pcm: added active flag; tested cell voice/data
2020-08-09 uart dirty property added
2020-12-04 stereo audio out; lvds display; LSM9DS1 added
    [disp.sch, exp.sch, periph.sch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]
2021-02-24 i2c driver initial import
2021-02-28 net send will do selected spi dev pause/resume if more is set and netowk is not active
2021-03-29 added display adapter for focuslcds E50RG84885LWAM520-CA panel
    [display.kicad_pcb, display.sch]
2021-03-29 rev2 board
    [disp.sch, exp.sch, periph.sch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]
2021-03-29 added panel for rev2 board
    [display.kicad_pcb, panel.kicad_pcb, panel_empty.kicad_pcb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]
2021-03-29 added missing footprints
2021-03-29 renamed footprints
2021-03-29 moved i2c from esp32 to fe310. added bq25895, drv2605 and lsm9ds1 i2c support
2021-04-08 added board.h
2021-04-08 sdcard driver
2021-04-10 i2c refactor
2021-05-20 initial touch calibration fixed
2021-05-20 ov2460 camera sensor and arducam driver
2021-05-20 fat filesystem with disk encryption for sd card driver
2021-05-20 camera test app
2021-08-27 added esp32 spi daemon
2021-08-27 test app prints bq25895 regs
2021-08-27 net driver fixed
2021-08-27 added spi driver for imx8; added lwip tun driver
2021-08-27 temp commit for merge
    [disp.sch, display.kicad_pcb, display.sch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]
2021-08-27 added missing components/footprints
    [rvPhone.kicad_pcb]
2021-10-01 HW REV 3.0
    [breakout.kicad_pcb, breakout.sch, disp.sch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]
2021-11-16 board REV3 pins in board.h; eve BT817 support
2021-11-25 i2s init/start/running fixed; i2c start returns error if i2s is running
2021-11-25 spi display driver initial commit
2021-11-28 added pull-up pull-dn resistors; fixed input power;
    [disp.sch, exp.sch, periph.sch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]
2021-11-28 lcd driver added; fixed startup code;
2021-12-01 i2c added 16 bit register read/write
2021-12-07 fixed eve, spi start/stop interface
2021-12-23 REV3.1: - fixed audio - added spacers - UART is routed through audio mux instead of I2C - proper display connector alignment
    [disp.sch, display.kicad_pcb, display.sch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]
2022-03-21 i2s stereo driver
2022-08-05 adds a derivation that compiles the driver flake output. Co-authored-by: DieracDelta justin@restivo.me
2022-09-26 Add toolchain for fe310 and esp32 SoCs.
    Co-authored-by: Ctem <c@ctem.me>
    Co-authored-by: a-kenji <aks.kenji@protonmail.com>
    commit e882e362932886a644ddc0af293a5842adae0b34
    Author: nrdsp <52072404+nrdsp@users.noreply.github.com>
    Date: Wed Sep 14 11:56:24 2022 +0100
    Delete esp32-toolchain.nix
    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
